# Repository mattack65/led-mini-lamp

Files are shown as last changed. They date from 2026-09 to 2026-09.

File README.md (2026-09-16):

# LED Mini Lamp

An open-source, 3D-printable LED lamp powered by WLED.

<p align="center">
  First WLED-effect candidate.
  Second WLED-effect candidate.
</p>

<p align="center">
  Third WLED-effect candidate.
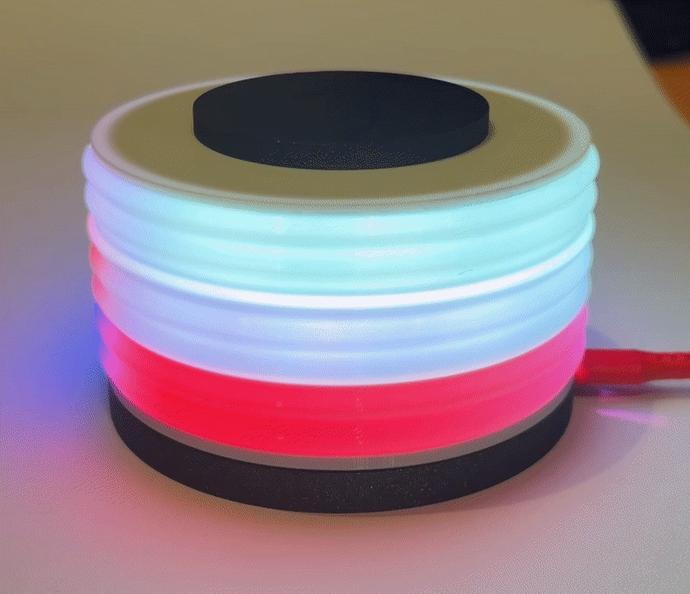
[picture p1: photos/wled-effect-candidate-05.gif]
Fifth WLED-effect candidate.
  
</p>

<p align="center">
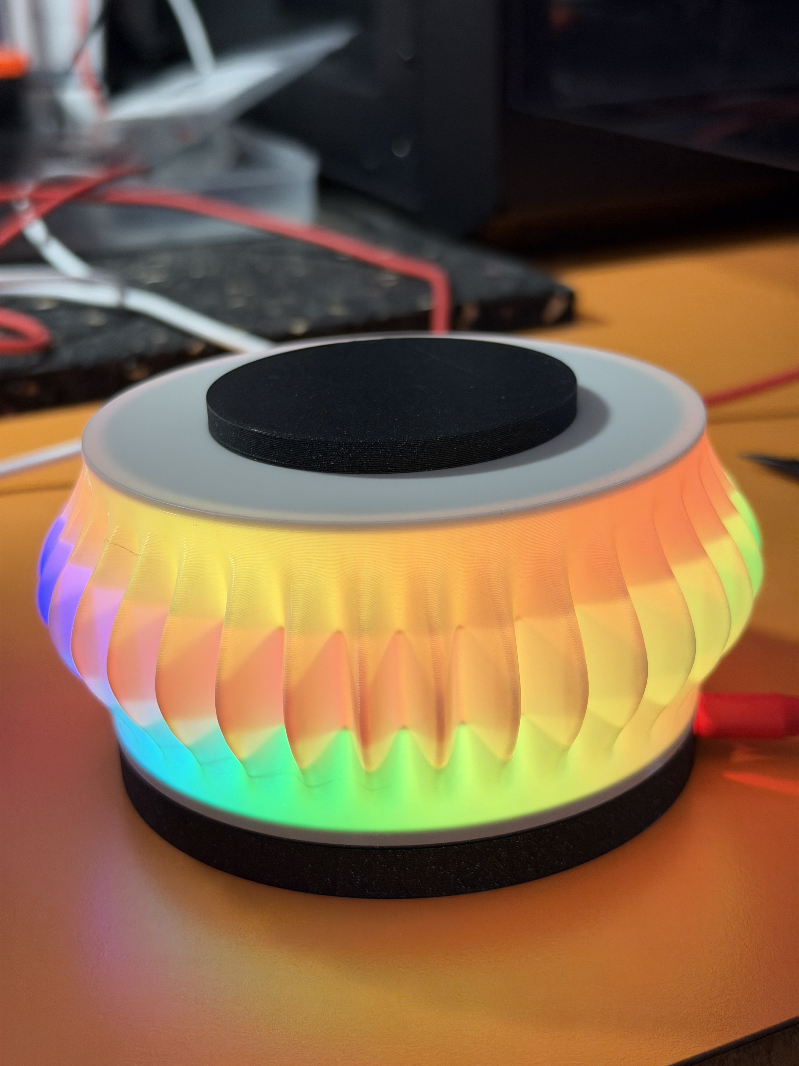
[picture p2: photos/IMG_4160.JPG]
LED Mini Lamp with a colourful WLED effect.
  
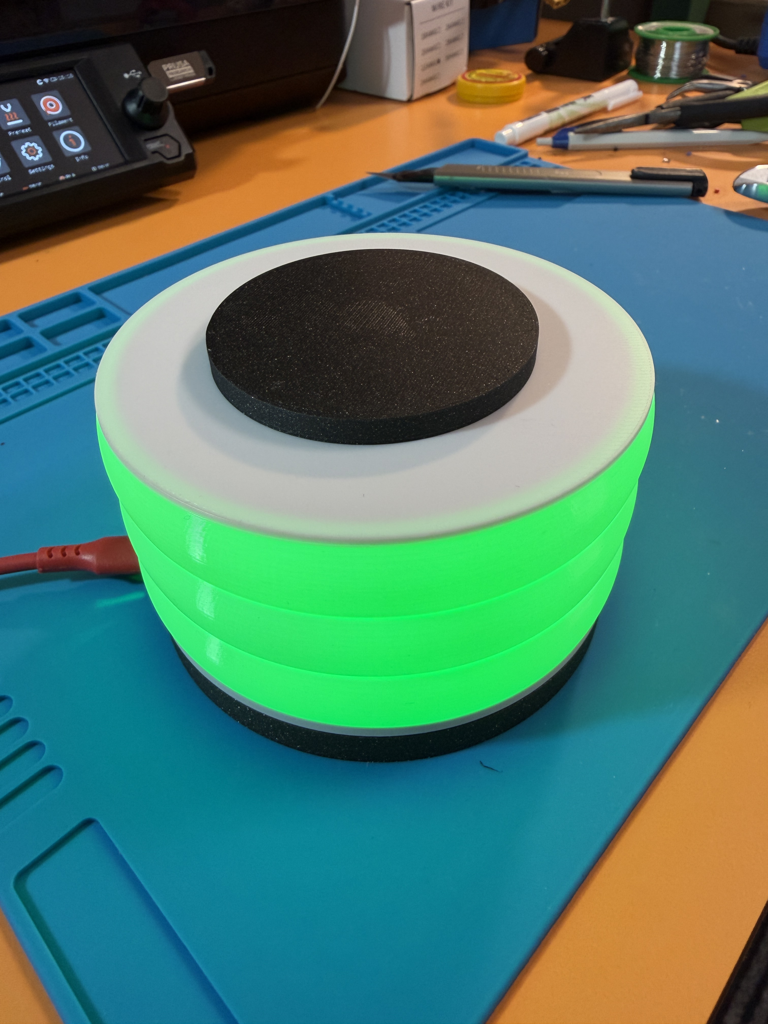
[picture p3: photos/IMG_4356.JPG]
LED Mini Lamp illuminated in green.
  
</p>

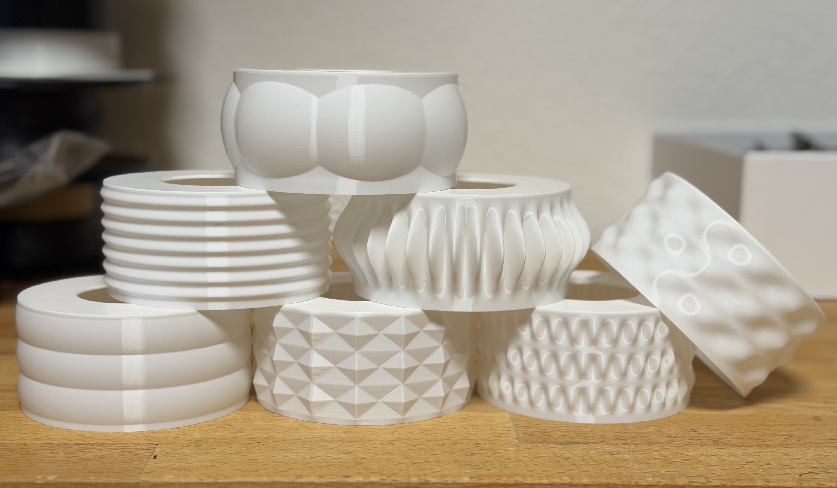
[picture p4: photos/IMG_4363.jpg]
The seven available white PLA diffusor designs.


## Start here

- [Bill of materials](docs/bom.md)
- [Printing the PLA parts](docs/printing.md)
- [Installing WLED firmware](docs/install-wled.md)
- [Setting up WLED](docs/wled-setup.md)
- [Assembly](docs/assembly.md)
- [Using your lamp](docs/using-your-lamp.md)

## Licence

This project is licensed under [CC BY-SA 4.0](LICENSE.md).

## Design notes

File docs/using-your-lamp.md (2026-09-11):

# Using your lamp

Control the lamp with the [WLED app](wled-setup.md#app-and-first-connection)
or by opening its WLED address in a browser.

## Colours and effects

Open the **Colors** tab to choose colours and palettes. Open the **Effects**
tab to browse animations, then adjust brightness, speed, and intensity until
you find a look you like.

## Save presets

Presets save a complete look: colours, effect, brightness, and other current
settings. They are useful for switching between favourite moods with one tap.

1. Set the lamp exactly as you like it.
2. Open the **Presets** tab and choose **Create Preset**.
3. Give it a meaningful name, such as `Warm evening` or `Party`.
4. Save the current state.

Select a saved preset at any time to restore it. You can also create a
playlist to cycle through multiple presets automatically.

## On and off presets

Presets can also run a command rather than save a lighting look. In the
**Presets** tab, choose **Create Preset**, turn off **Use current state**, and
enter one of these API commands:

| Command | Result |
| --- | --- |
| `T=1` | Turn the lamp on, restoring the last-used look. |
| `T=0` | Turn the lamp off. |
| `T=2` | Toggle the lamp on or off. |

Save these with clear names such as `Lamp on` and `Lamp off`. They can be
selected manually, used in playlists, or triggered by a schedule.

## Turn on at sunset

1. Create and save the preset you want the lamp to use at sunset. To simply
   restore the last-used look, create a `T=1` on preset instead. Also create a
   `T=0` off preset for the time you want the lamp to switch off.
2. Open **Config → Time & Macros**.
3. Set the correct time zone and enable time synchronisation (NTP).
4. Set your location so WLED can calculate local sunrise and sunset. When
   using a browser, the **Get Location** button can fill this in.
5. Under **Time-Controlled Presets**, add a **Sunset** timer, select your
   preset, choose the days of the week, and save.

Use the minutes field to make the lamp switch on before or after sunset. Add a
second timer for sunrise, sunset, or a regular time and select the `T=0` off
preset to switch it off automatically.

## Other useful WLED features

- **Nightlight:** have the lamp fade itself off after a chosen duration.
- **Boot preset:** choose a preset that is applied automatically whenever the
  lamp receives power.
- **Playlists:** create a slow, changing ambience from several presets.
- **Home Assistant:** WLED has native Home Assistant discovery, so the lamp
  can be added to an existing smart-home setup.

WLED has many more options; its [official documentation](https://kno.wled.ge/)
is an excellent place to explore once the lamp is working.

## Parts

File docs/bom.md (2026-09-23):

# Bill of materials

## Electronics and consumables

Estimated costs are approximate, exclude shipping, and use EUR. AliExpress
prices and availability vary by destination and over time.

| Part | Quantity | Specification | Estimated cost | Notes / source |
| --- | ---: | --- | ---: | --- |
| ESP32 development board | 1 | Small, flat ESP32 board with USB port | ~€2.60 | Tested: LOLIN S2 Mini. ESP32-C3 Super Mini is planned for future builds. The board must fit inside the lamp base; boards larger than the S2 Mini may not fit. Use a board without pre-soldered pin headers or other protruding hardware. The USB port must remain accessible because it provides power and is used for setup. [Example ESP32-C3 SuperMini listing](https://www.aliexpress.com/item/1005011660038502.html) |
| Addressable LED strip | 1 | 35 LEDs; 60 LEDs/m; WS2812B ECO; IP30 | Under €2.00 | Tested: BTF-LIGHTING WS2812B ECO. The 60 LEDs/m spacing is required. 35 LEDs use about 60 cm of strip. ECO LEDs keep the full-white load suitable for ordinary USB power. [Find the exact specification on AliExpress](https://www.aliexpress.com/w/wholesale-ws2812b-eco-60-leds-m-ip30.html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) |
| Hook-up wire | 3 lengths | AWG22; about 7 cm each | ~€0.10 | Enough for the maximum LED current of 1.12 A. One wire each for 5 V, GND, and data. |
| Double-sided VHB tape | About 2 cm² | Suitable for electronics | ~€0.05 | Holds the ESP32 to the base. |
| Glue | A few drops | Suitable for the printed parts | ~€0.05 | Glues the clip unit into the top plug. |
| Solder | As needed | Electronics solder | ~€0.05 | The LED strip connects to the ESP32 with six solder joints. |
| 3D-printed parts | 1 set | Base, top plug, clip unit, three core structures, and one diffusor | ~€2.47 | See the [print files](../print-files/) and [print settings](printing.md). |
| **Total material cost** | **1 lamp** | **All parts above** | **Under €7.32** | Excludes the USB cable, power adapter, and soldering iron. |

## Power requirement

A USB cable and power adapter are required but intentionally not included in
the BOM: most builders already have a suitable set.

| Part | Quantity | Requirement | Estimated cost |
| --- | ---: | --- | ---: |
| USB cable and power adapter | 1 | 5 V; at least 1.5 A. Connects to the ESP32 USB port and powers the lamp. | Not included |

## Tools

| Tool | Quantity | Estimated cost | Notes |
| --- | ---: | ---: | --- |
| Soldering iron | 1 | Not included | Suitable for electronics soldering. |

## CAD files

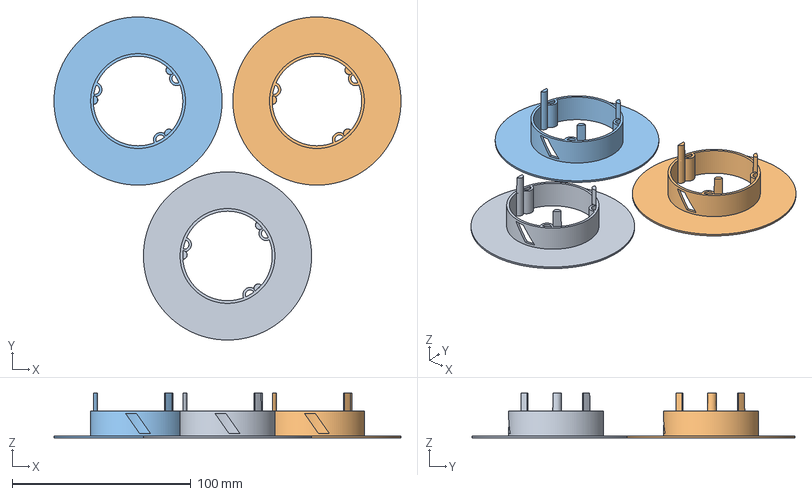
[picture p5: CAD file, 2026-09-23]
print-files/3mf/lamp_core_structure.3mf
194.0 x 180.6 x 25.0 mm

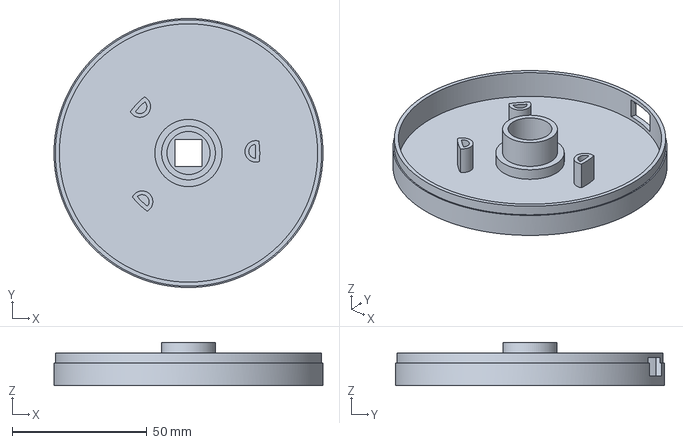
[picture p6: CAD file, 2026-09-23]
print-files/3mf/lamp_base.3mf
100.0 x 100.0 x 16.0 mm

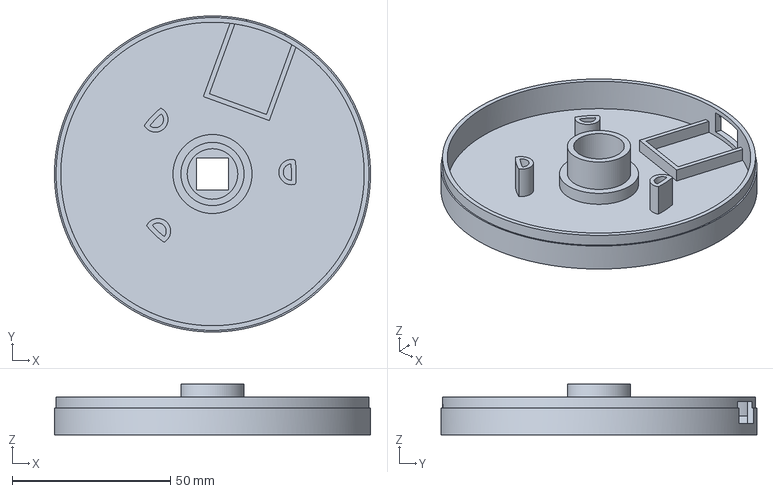
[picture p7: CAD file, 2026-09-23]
print-files/3mf/lamp_base_c3_super_mini.3mf
100.0 x 100.0 x 16.0 mm

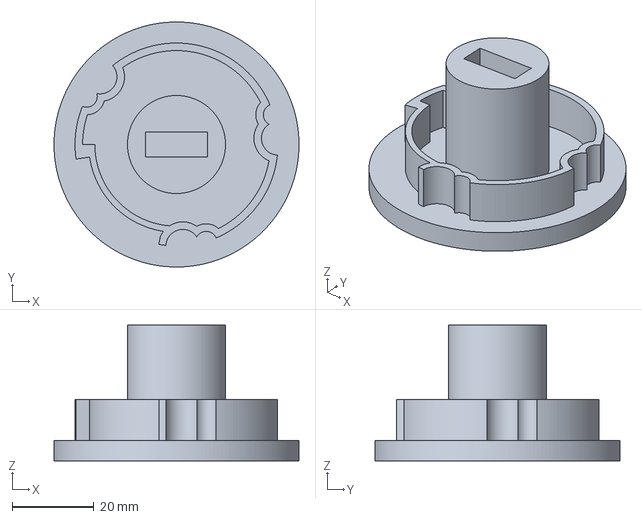
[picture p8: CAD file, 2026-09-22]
print-files/3mf/lamp_top_plug.3mf
60.0 x 60.0 x 33.3 mm

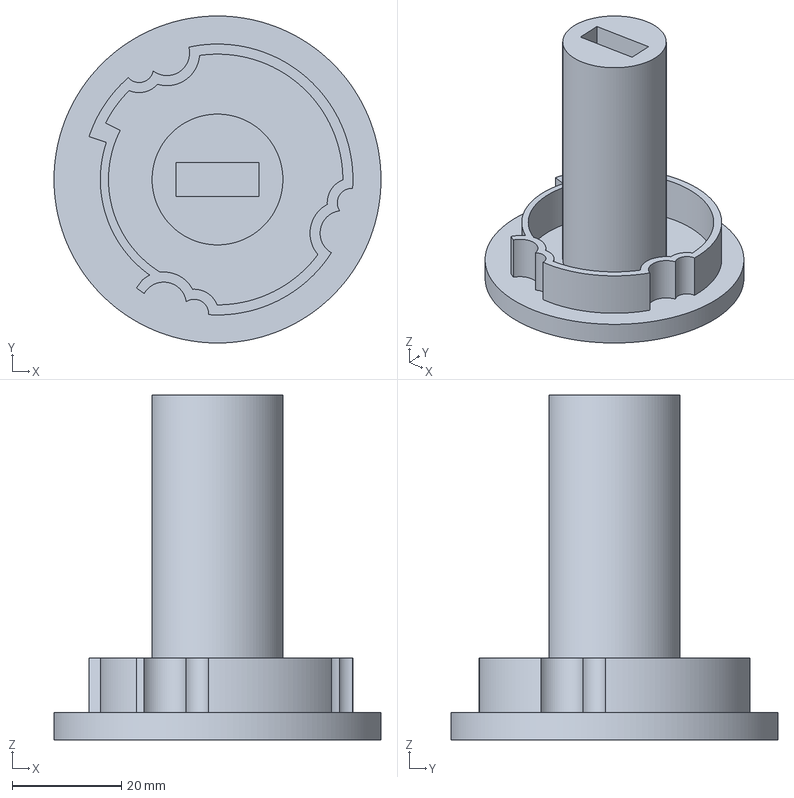
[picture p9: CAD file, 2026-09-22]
print-files/3mf/lamp_top_plug_5_layers.3mf
60.0 x 60.0 x 63.3 mm

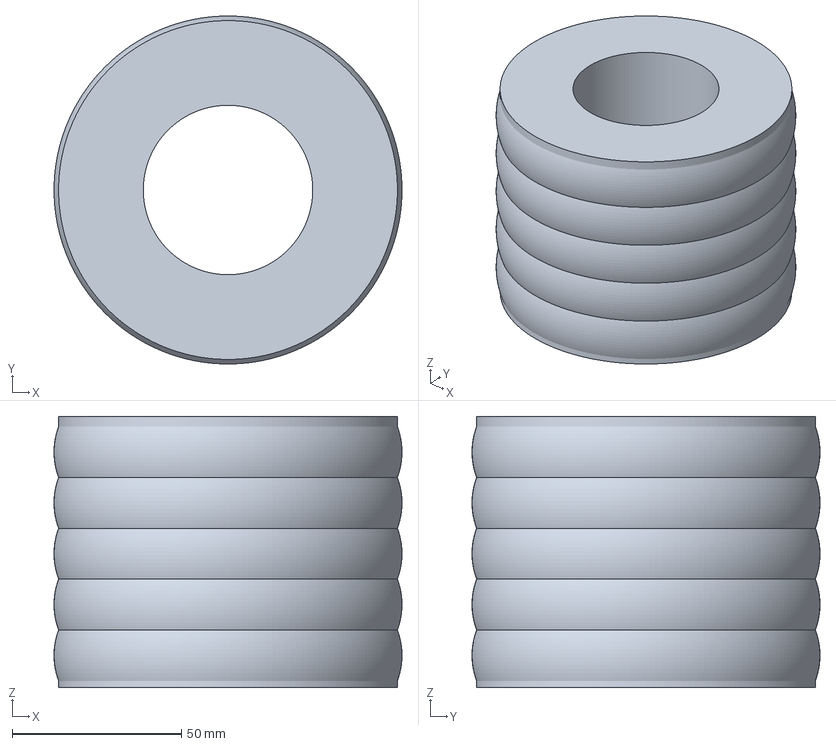
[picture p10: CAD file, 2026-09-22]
print-files/3mf/lamp_diffusor_bulges_5_layers.3mf
102.7 x 102.7 x 80.0 mm

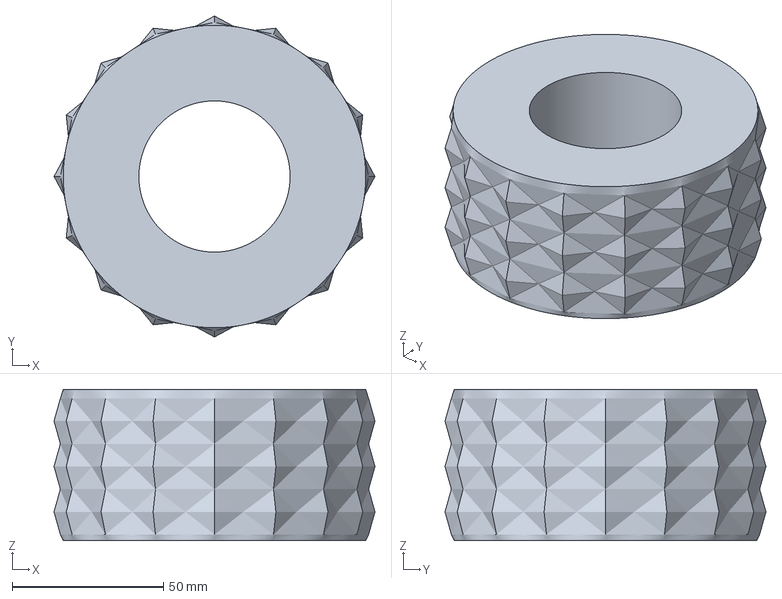
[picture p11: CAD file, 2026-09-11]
print-files/3mf/lamp_diffusor_starburst.3mf
106.2 x 106.2 x 50.0 mm

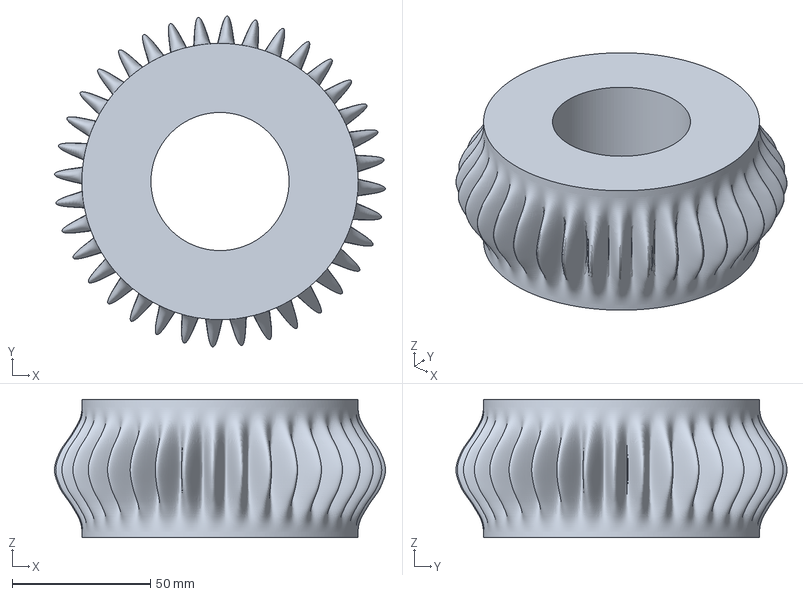
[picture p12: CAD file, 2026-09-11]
print-files/3mf/lamp_diffusor_single_sinusoidal_bulge.3mf
119.9 x 119.9 x 50.0 mm

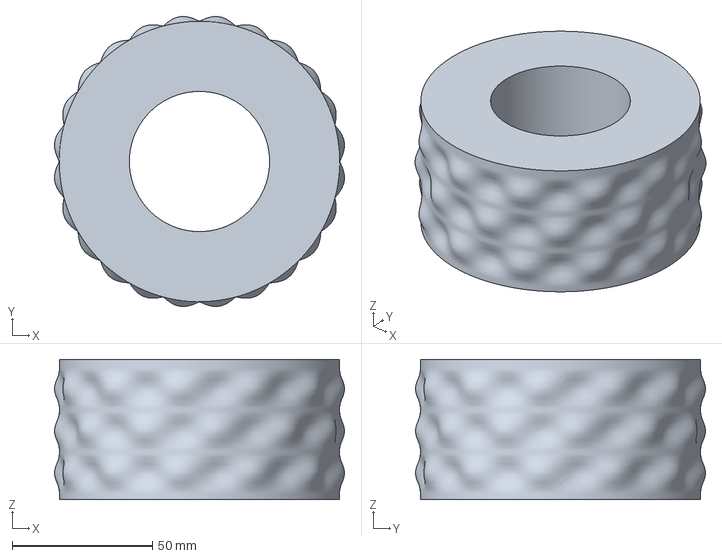
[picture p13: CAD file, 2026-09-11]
print-files/3mf/lamp_diffusor_sinusoidal_12_bubbles.3mf
103.4 x 103.4 x 50.0 mm

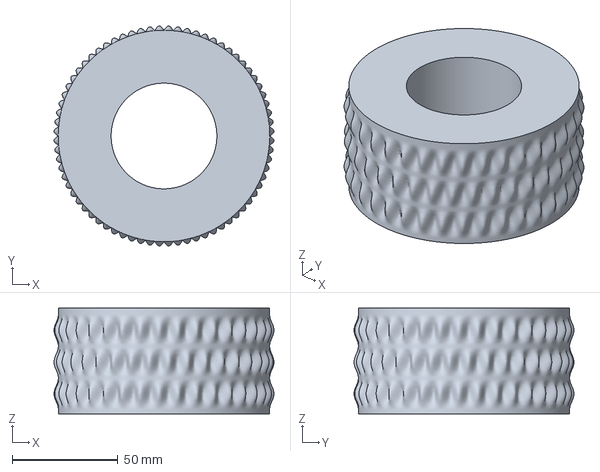
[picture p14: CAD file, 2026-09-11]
print-files/3mf/lamp_diffusor_sinusoidal_36_wave_x3.3mf
104.1 x 104.1 x 50.0 mm

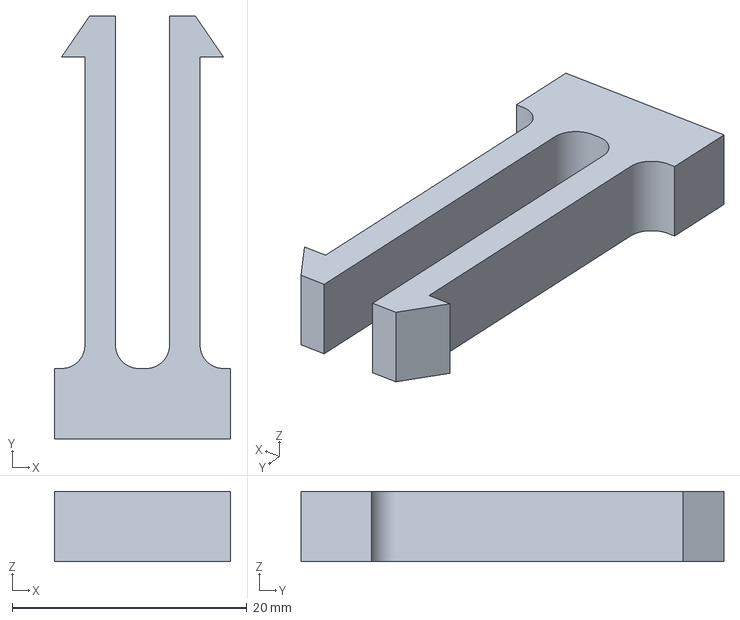
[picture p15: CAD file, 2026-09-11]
print-files/3mf/lamp_clip_unit.3mf
15.0 x 36.0 x 6.00 mm

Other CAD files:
print-files/3mf/lamp_diffusor_pumpkin.3mf
print-files/3mf/lamp_diffusor_seven_ripple.3mf
print-files/3mf/lamp_diffusor_bulges.3mf
print-files/stl/lamp_base.stl
print-files/stl/lamp_base_c3_super_mini.stl
print-files/stl/lamp_clip_unit.stl
print-files/stl/lamp_core_structure.stl
print-files/stl/lamp_diffusor_bulges.stl
print-files/stl/lamp_diffusor_bulges_5_layers.stl
print-files/stl/lamp_diffusor_pumpkin.stl
print-files/stl/lamp_diffusor_seven_ripple.stl
print-files/stl/lamp_diffusor_single_sinusoidal_bulge.stl
print-files/stl/lamp_diffusor_sinusoidal_12_bubbles.stl
print-files/stl/lamp_diffusor_sinusoidal_36_wave_x3.stl
print-files/stl/lamp_diffusor_starburst.stl
print-files/stl/lamp_top_plug.stl
print-files/stl/lamp_top_plug_5_layers.stl

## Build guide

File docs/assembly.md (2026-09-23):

# Assembly

This guide uses a LOLIN S2 Mini and a 35-LED WS2812B ECO strip. First install [WLED](install-wled.md) on the ESP32. The assembly photos use red for 5 V, black for GND, and purple for data.

## 1. Prepare the parts

The [printed parts](printing.md) are three core structures, a base, a top plug, a clip unit, and one diffusor. You will also need the controller, the LED strip, three short wires, double-sided VHB tape, glue, and soldering equipment.

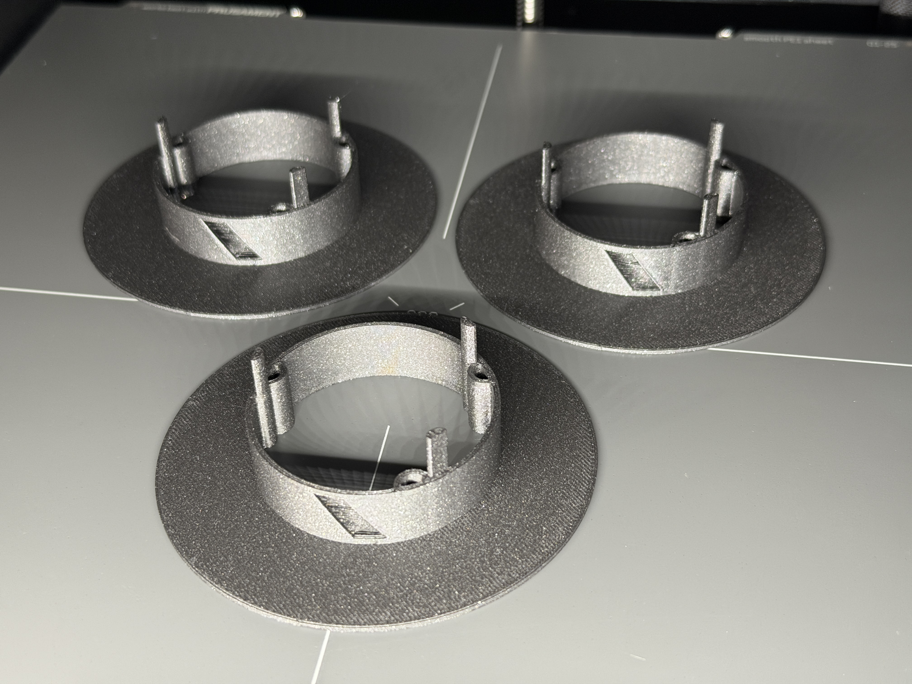
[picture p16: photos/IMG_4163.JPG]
Three printed core structures on the print plate.


The core structures.

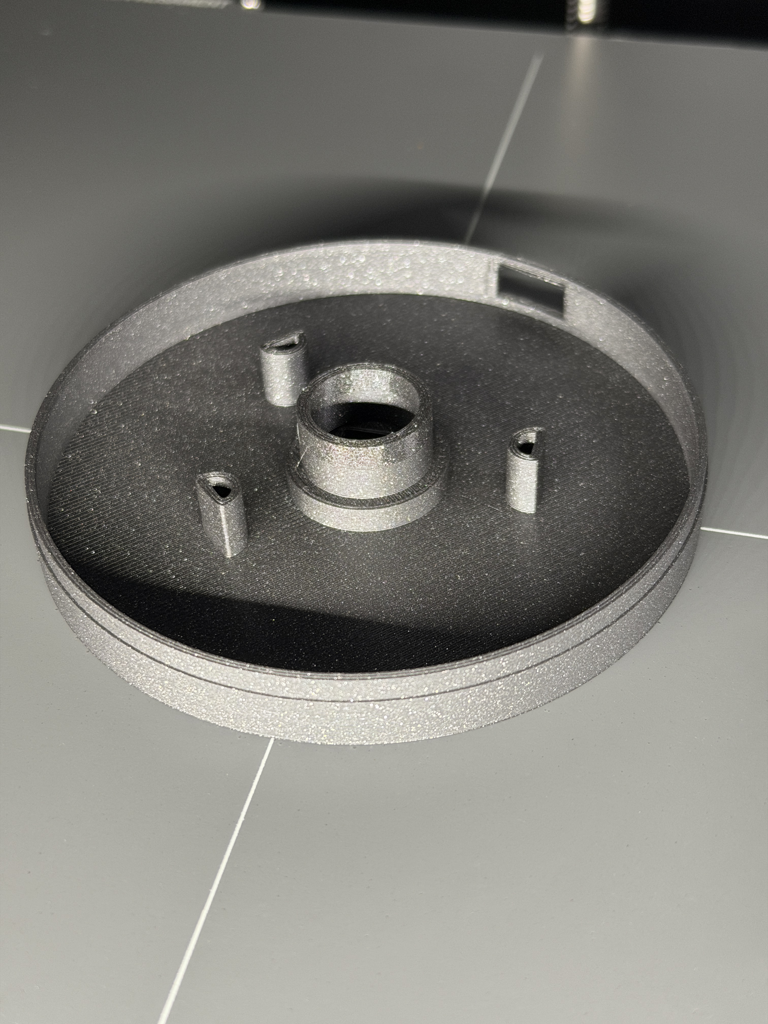
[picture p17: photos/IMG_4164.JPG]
The printed base, viewed from above.


The base holds the controller and leaves the USB port accessible at its edge.

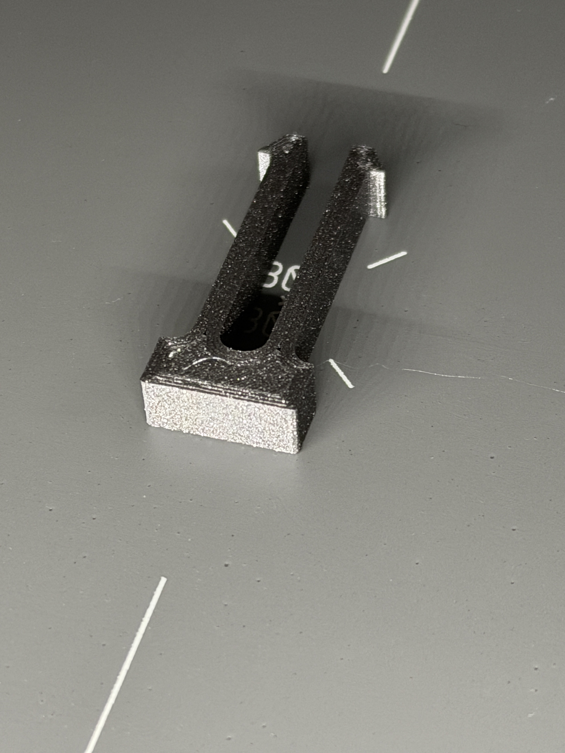
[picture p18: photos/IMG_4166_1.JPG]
The printed clip unit.


The clip unit will later be glued into the top plug.

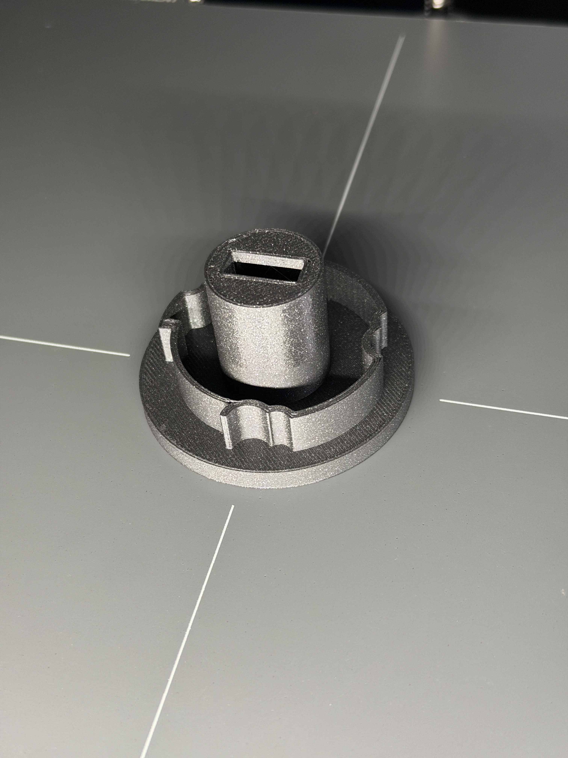
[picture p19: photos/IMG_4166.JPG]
The printed top plug.


The top plug closes the centre opening once the lamp is complete.

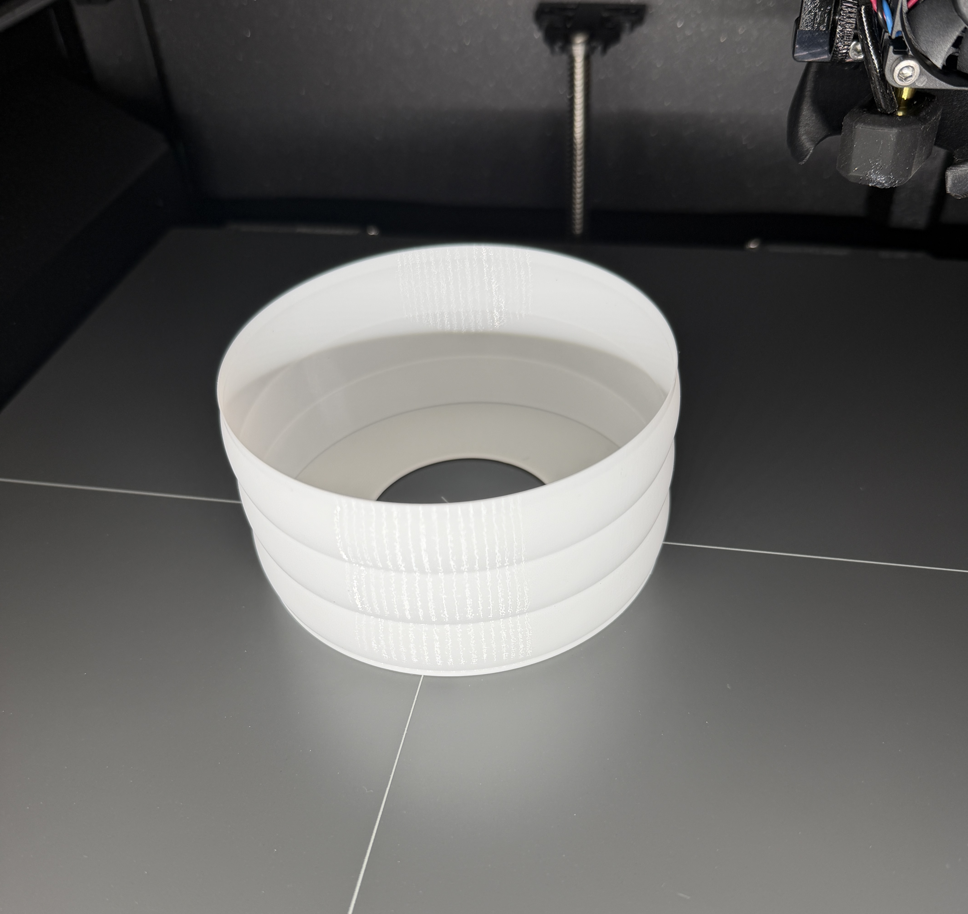
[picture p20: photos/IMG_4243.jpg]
A finished white PLA diffusor.


Choose one white-PLA diffusor for this lamp.

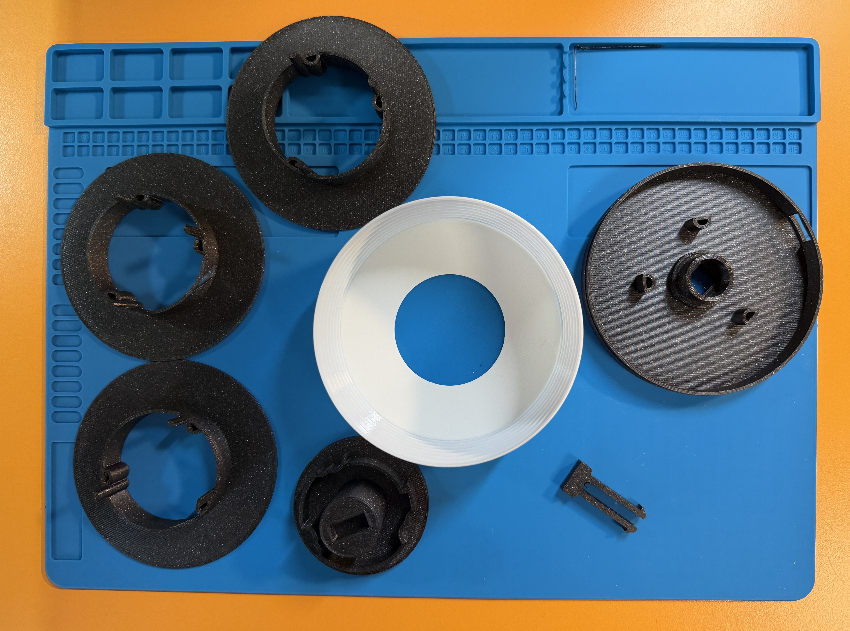
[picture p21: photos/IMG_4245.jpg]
All printed parts arranged before assembly.


All the 3D-printed parts.

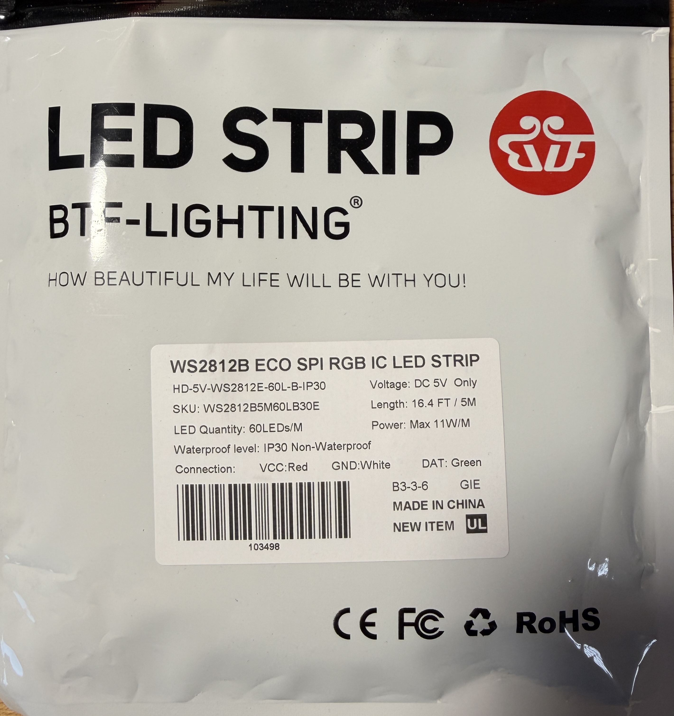
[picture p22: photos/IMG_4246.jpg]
BTF-LIGHTING WS2812B ECO LED strip packaging.


Use a 60 LEDs/m WS2812B ECO strip, as listed in the [BOM](bom.md).

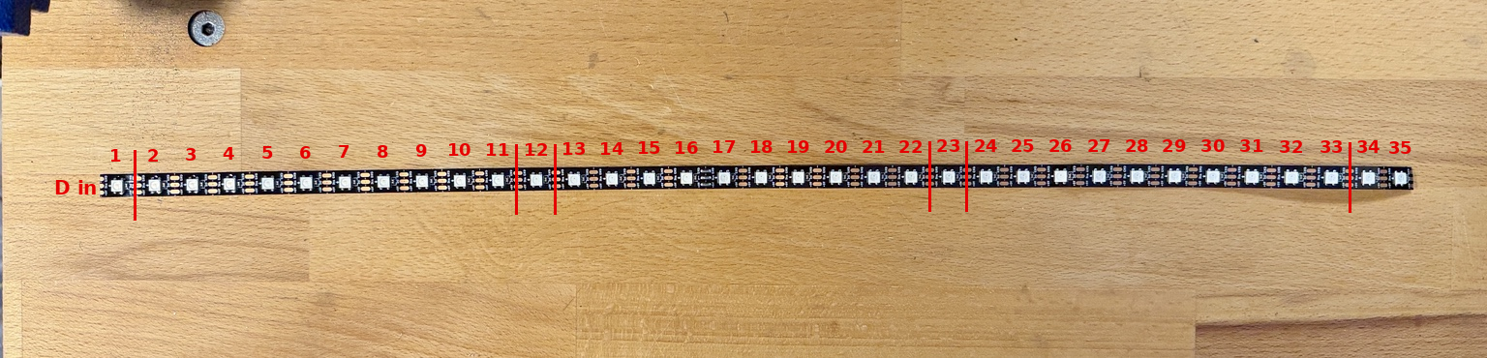
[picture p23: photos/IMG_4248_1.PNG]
A 35-LED length marked on the LED strip.


Some LED strips have factory-soldered joins between sections. The red lines mark the folds required when fitting the strip, counted from the "D in" end. Before cutting a 35-LED section, check that no factory-soldered join will land on a fold. If it would, cut one or two LEDs from the start of the roll first, then choose the next 35-LED section.

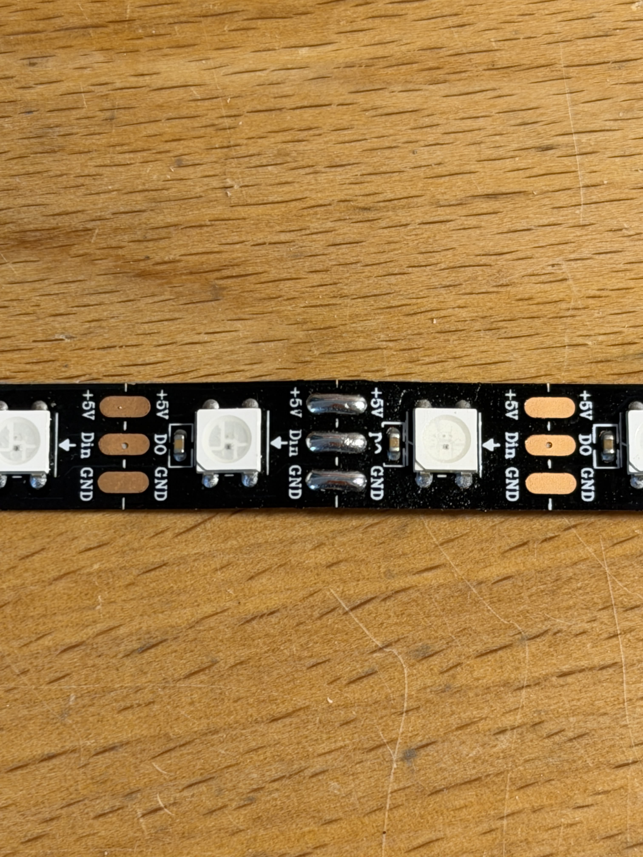
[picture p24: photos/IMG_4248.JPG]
Close-up of the LED strip.


This factory-soldered join is fine on a straight section of the strip, but it must not fall on one of the marked folding positions.

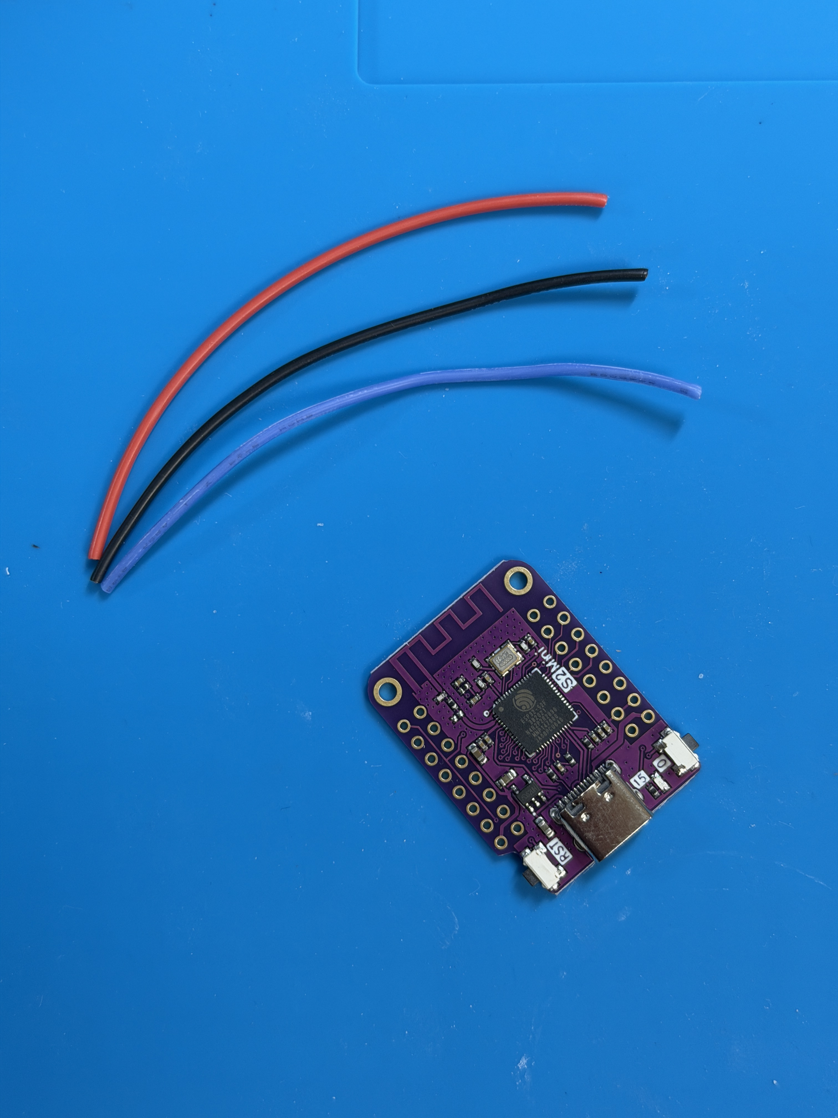
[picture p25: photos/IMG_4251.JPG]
LOLIN S2 Mini and three prepared wires.


Prepare three wires about 7 cm long: one each for 5 V, GND, and data.

## 2. Prepare the core and top clip

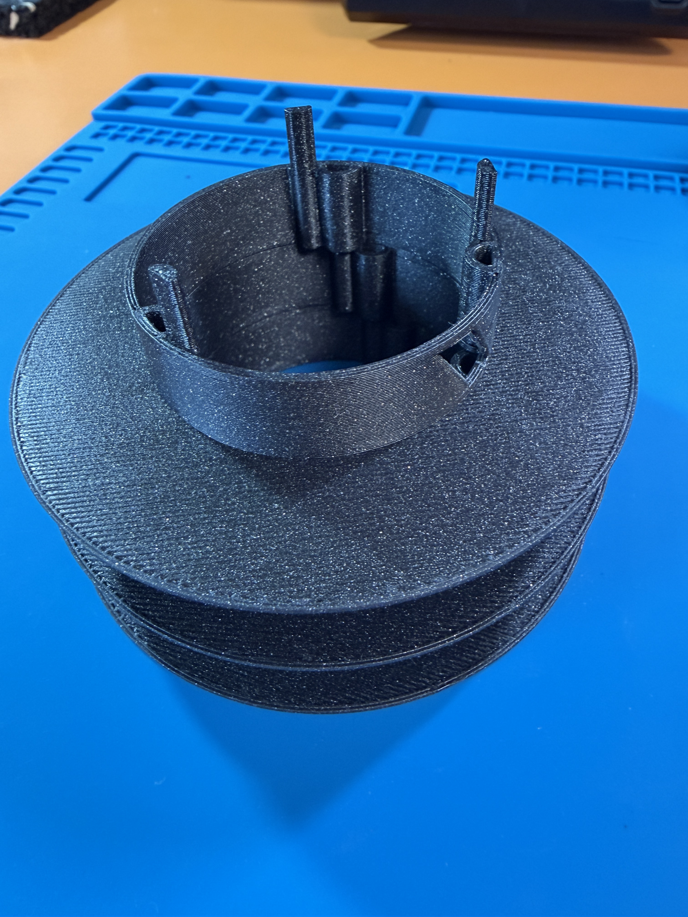
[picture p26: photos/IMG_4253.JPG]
The core structures assembled into the lamp frame.


Join the three core structures to make the internal frame. Their circular rings create the path for the LED strip.

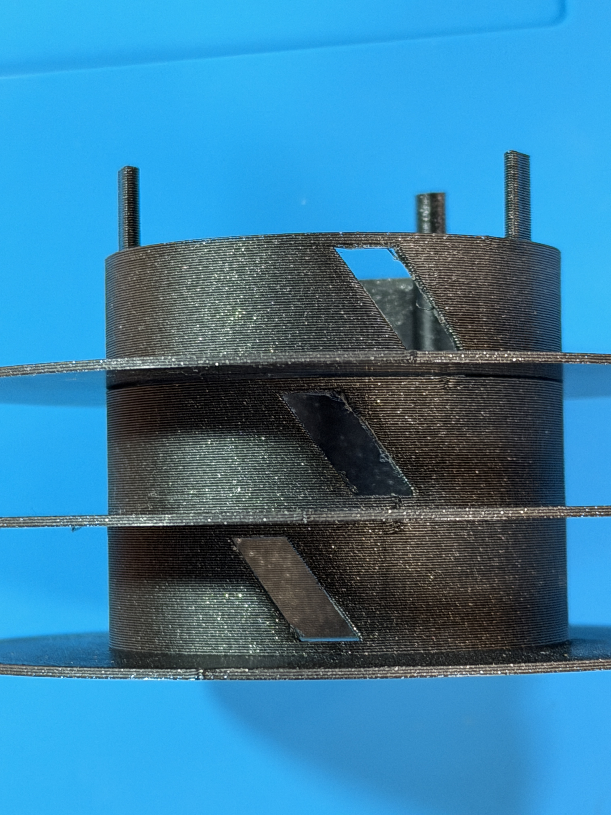
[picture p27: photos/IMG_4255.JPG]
Side view of the joined core structures.


Check that the core sections sit fully together.

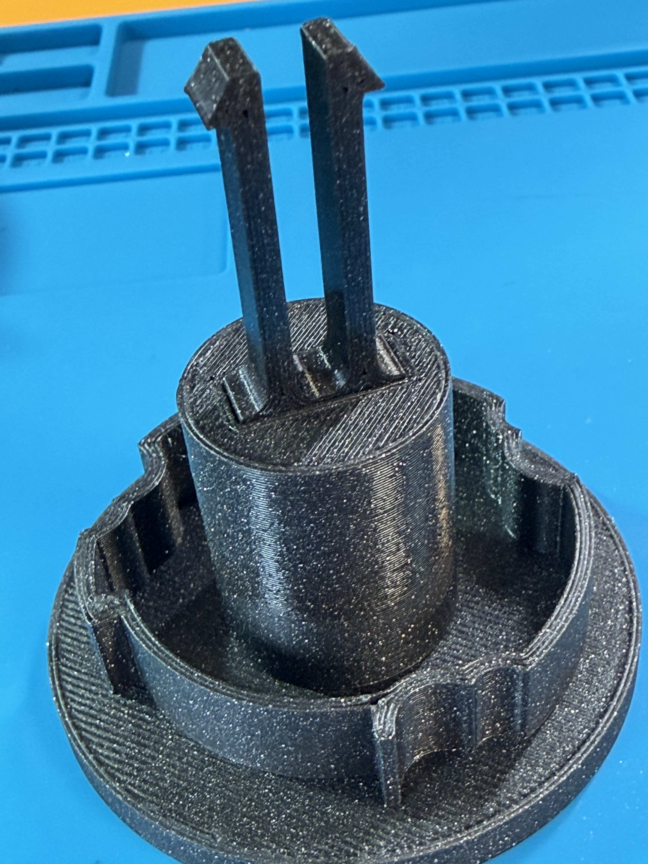
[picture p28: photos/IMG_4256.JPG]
Test-fitting the clip unit into the top plug.


Test-fit the clip into the top plug before gluing it in.

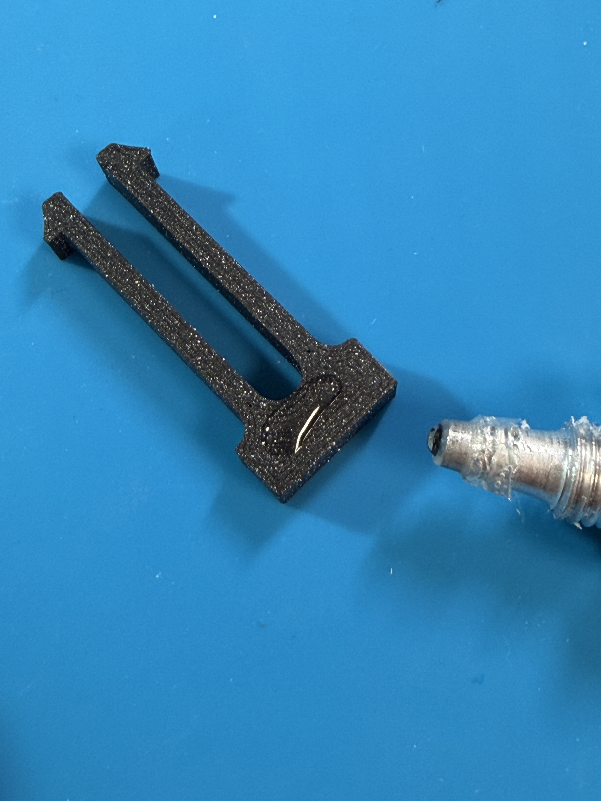
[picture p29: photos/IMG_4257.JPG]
The clip unit and a few drops of glue.


Use only a few drops of glue for the clip unit.

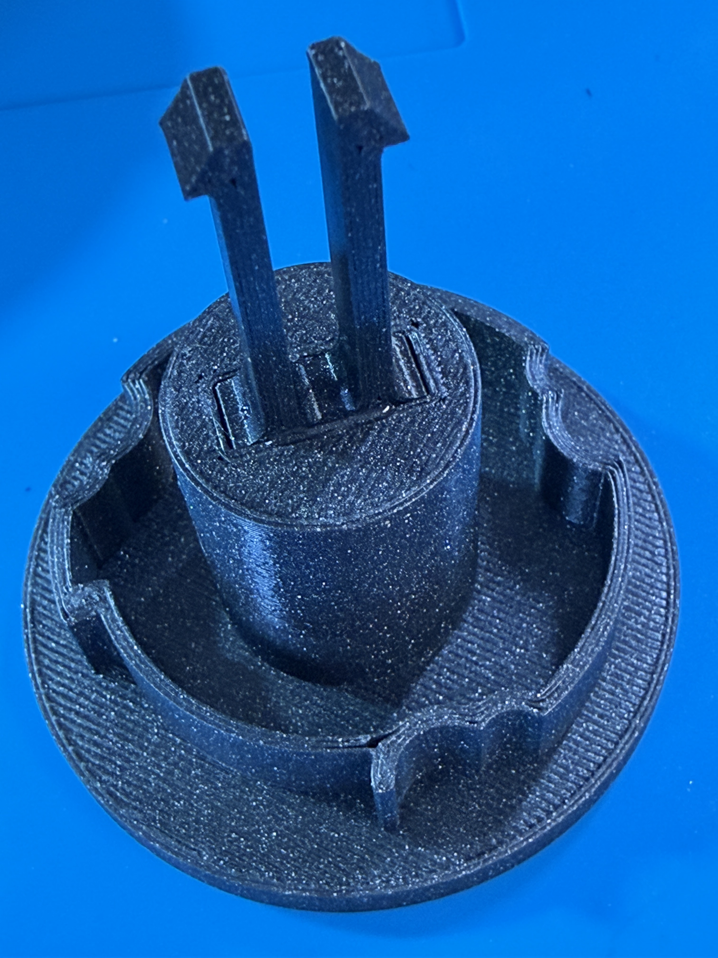
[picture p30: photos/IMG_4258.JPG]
The clip unit fitted into the top assembly.


Seat the clip unit squarely and press it all the way in. It should be flush.

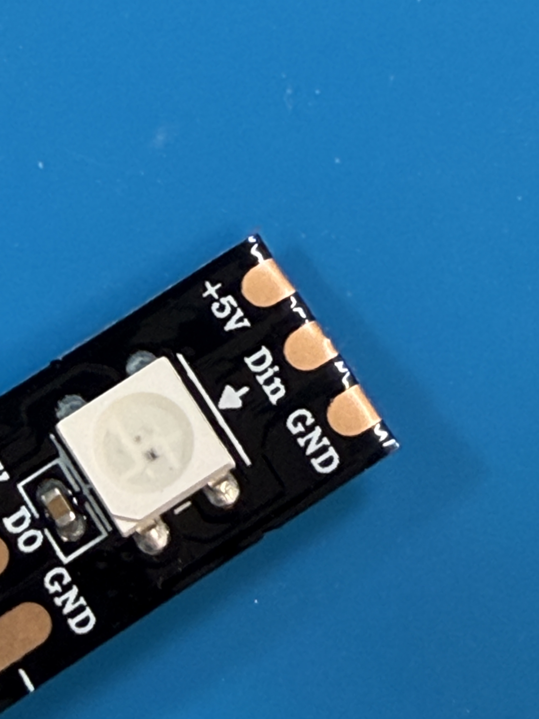
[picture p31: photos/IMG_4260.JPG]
LED strip pads at the data-input end.


The three pads are labelled +5V, D in, and GND. These are the pads to connect to the controller.

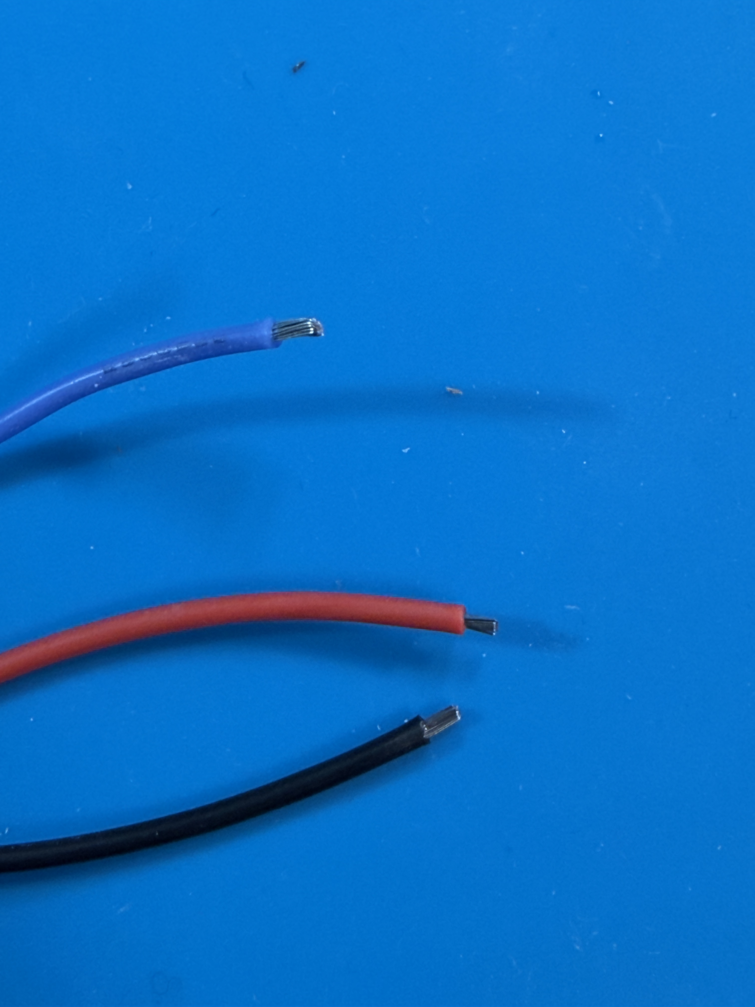
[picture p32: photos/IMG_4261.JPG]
Three wires with their ends stripped.


Strip only a few millimetres of insulation from each wire.

## 3. Solder the ESP32

The photos below show the pads on the LOLIN S2 Mini used in this build. On a different board, connect the same three signals: 5 V, GND, and the configured data GPIO.

| Function | LOLIN S2 Mini pad | LED strip pad | Wire shown |
| --- | --- | --- | --- |
| Power | VBUS | +5V | Red |
| Ground | GND | GND | Black |
| Data | 16/17 (GPIO 16) | D in | Purple |

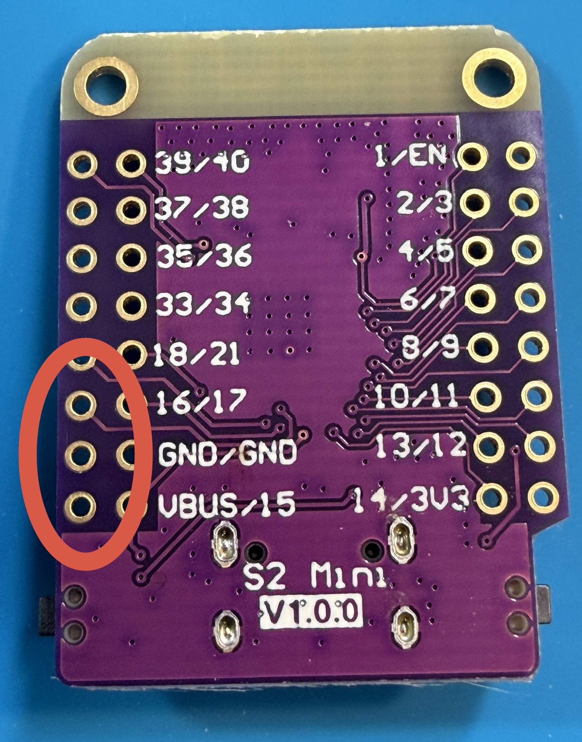
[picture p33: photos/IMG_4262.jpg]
LOLIN S2 Mini pads selected for the three connections.


The highlighted pads are, from top to bottom, GPIO 16, GND, and VBUS.

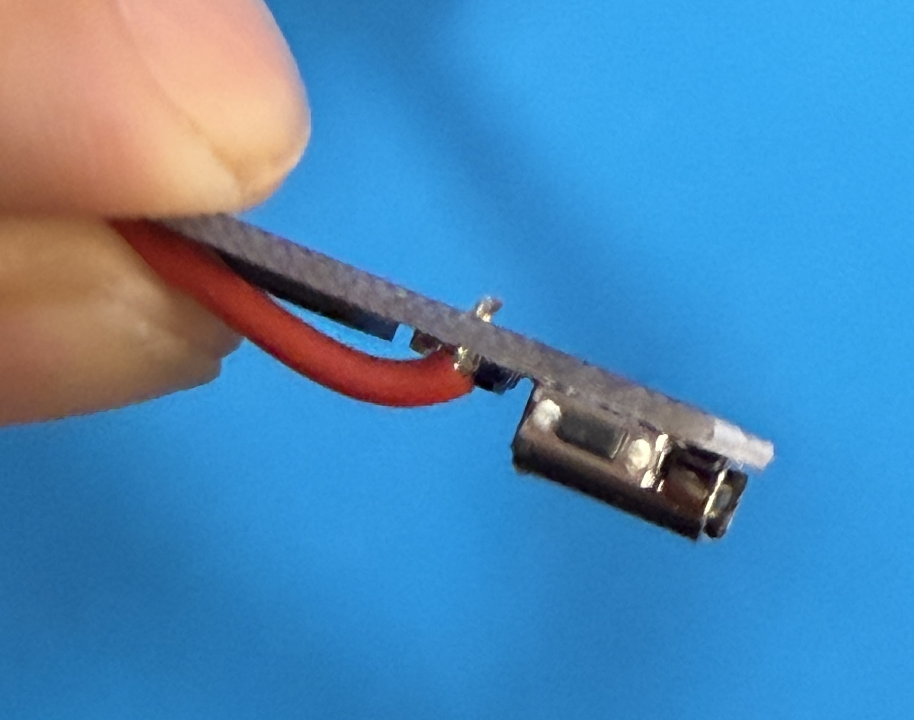
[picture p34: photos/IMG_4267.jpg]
Threading a wire through the ESP32 pad.


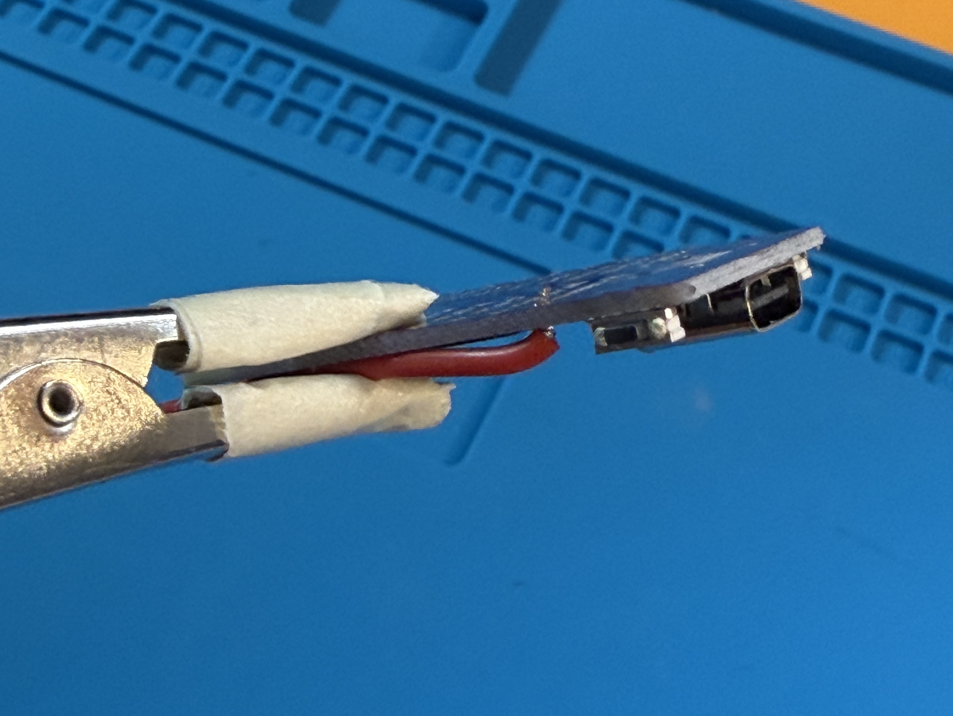
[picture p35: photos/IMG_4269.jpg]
A wire held ready for soldering.


A helping hand or similar holder makes these small solder joints much easier.

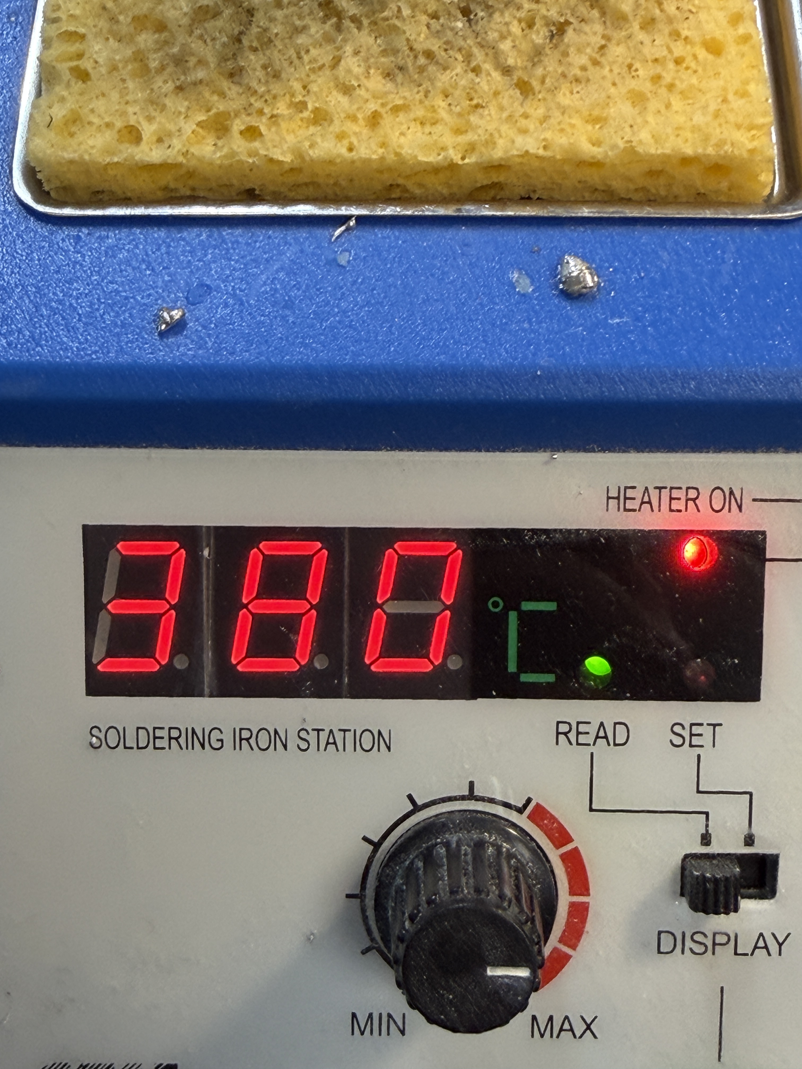
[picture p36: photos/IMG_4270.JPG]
Soldering-iron temperature set for the joint.


Heat your iron to about 380 °C.

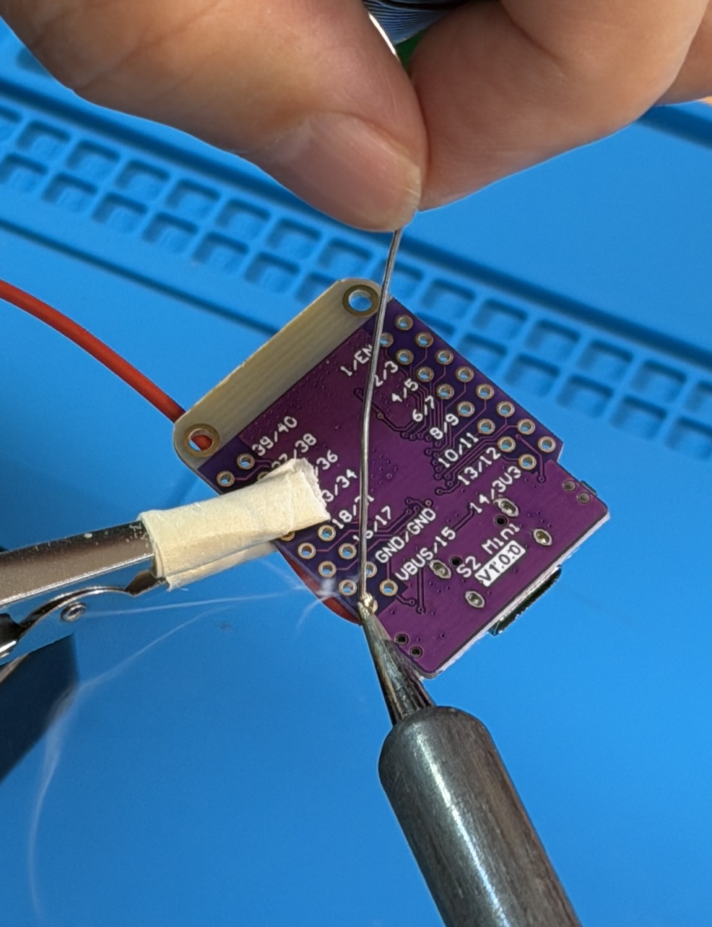
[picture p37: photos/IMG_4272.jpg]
Soldering the 5 V wire to the ESP32.


Solder the red 5 V wire to VBUS.

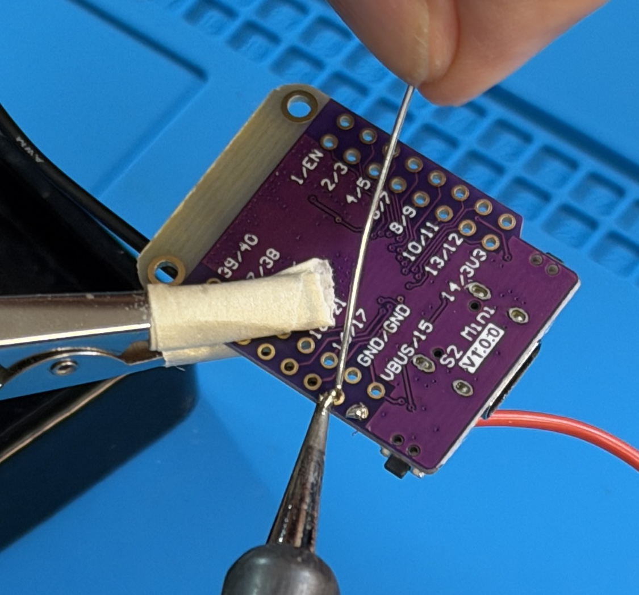
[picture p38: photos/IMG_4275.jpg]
Soldering the ground wire to the ESP32.


Solder the black wire to GND.

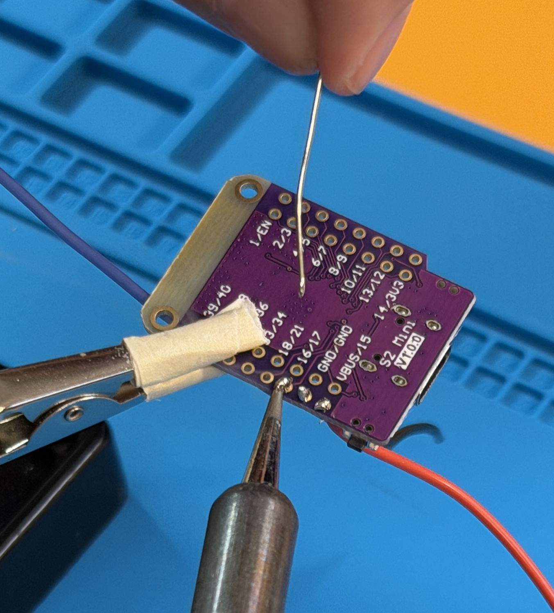
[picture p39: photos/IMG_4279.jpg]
Soldering the data wire to the ESP32.


Solder the purple data wire to GPIO 16.

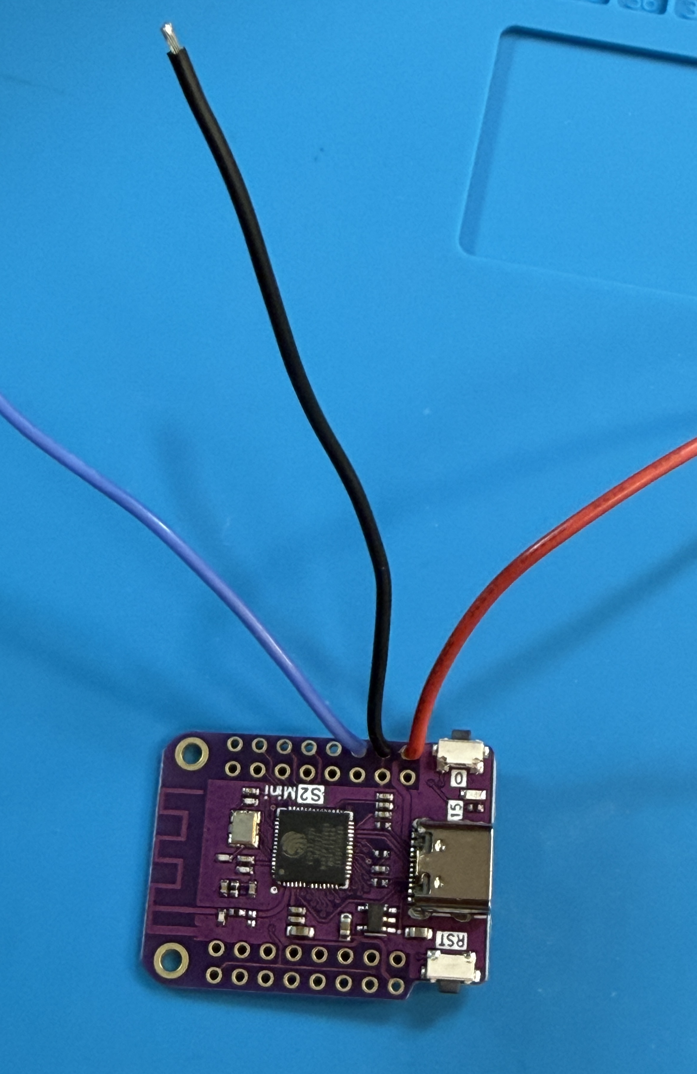
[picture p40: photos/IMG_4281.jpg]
ESP32 with all three wires connected.


The controller wiring is complete: red to VBUS, black to GND, and purple to GPIO 16.

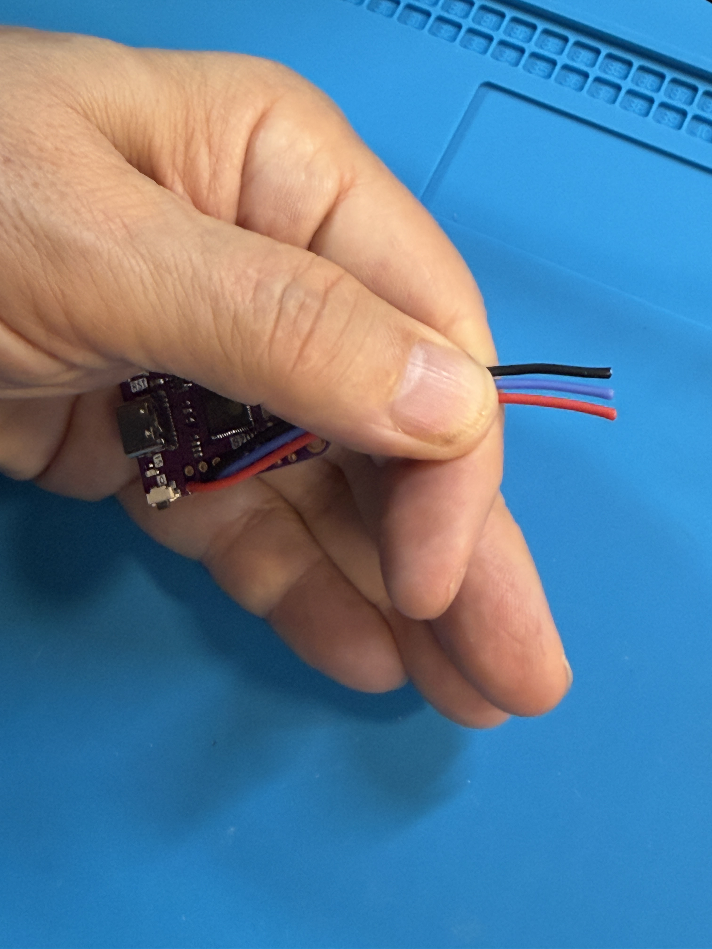
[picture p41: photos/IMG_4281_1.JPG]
Cutting the three wires to equal length.


Cut the free ends to the same length and arrange them in the correct order: red, purple, black.

## 4. Solder the LED strip

Solder the other ends of the same three wires to the +5V, D in, and GND pads at the **input** end of the LED strip. The three controller joints and the three strip joints are the six solder joints required for the lamp.

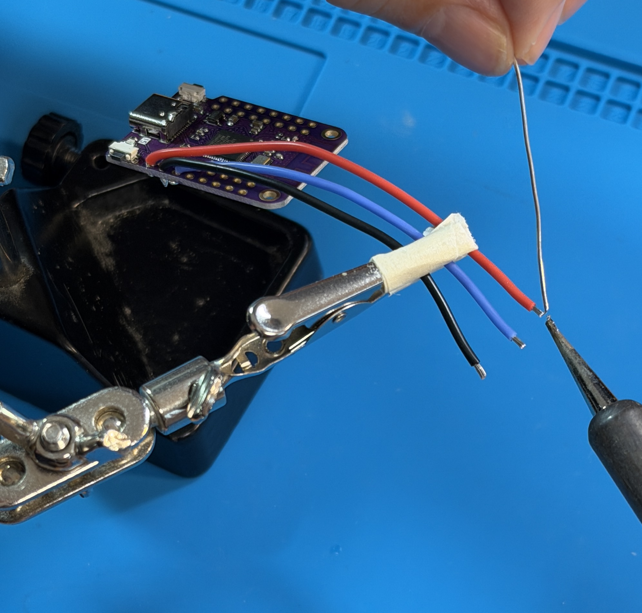
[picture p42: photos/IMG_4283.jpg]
Preparing the wires for the LED-strip connection.


Tin the ends of the wires.

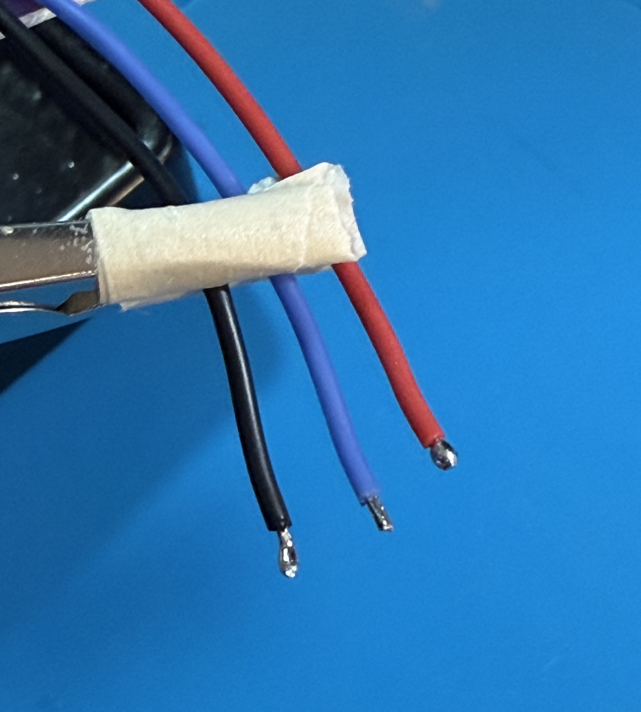
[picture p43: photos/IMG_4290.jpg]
The three wire ends tinned and ready.


A small amount of solder on each end is enough.

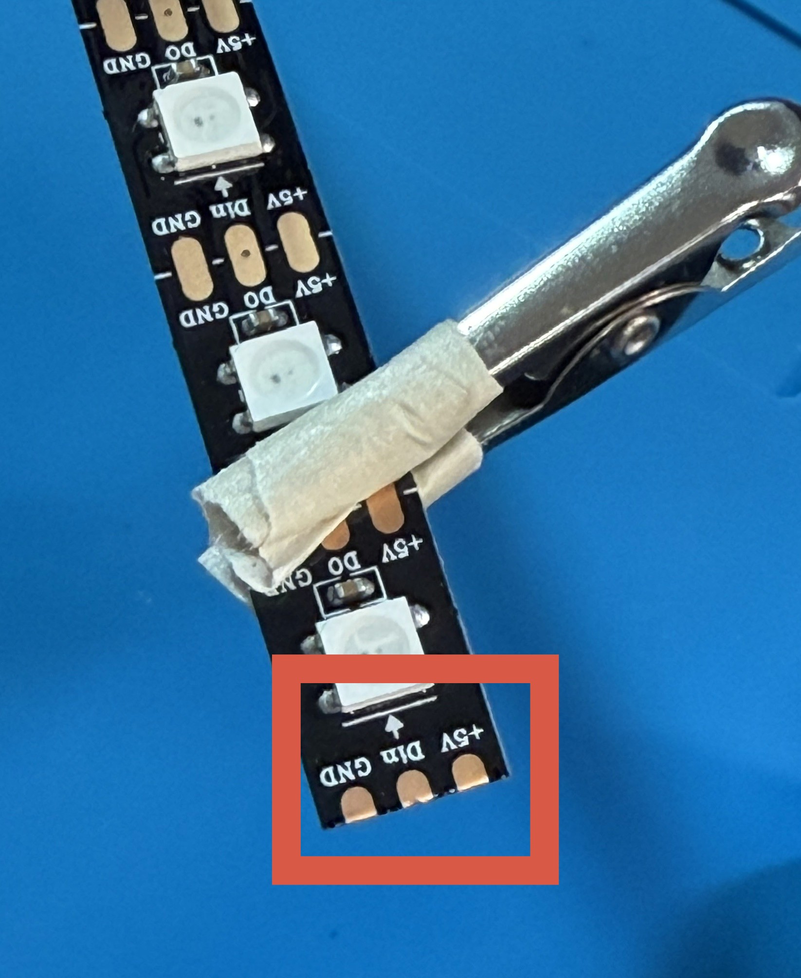
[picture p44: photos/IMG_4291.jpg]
LED-strip input pads highlighted.


The three pads are labelled +5V, D in, and GND. These are the pads to connect to the controller. Use the end marked D in; the arrows point away from this input end. If you solder the strip from the wrong end, it will not work later.

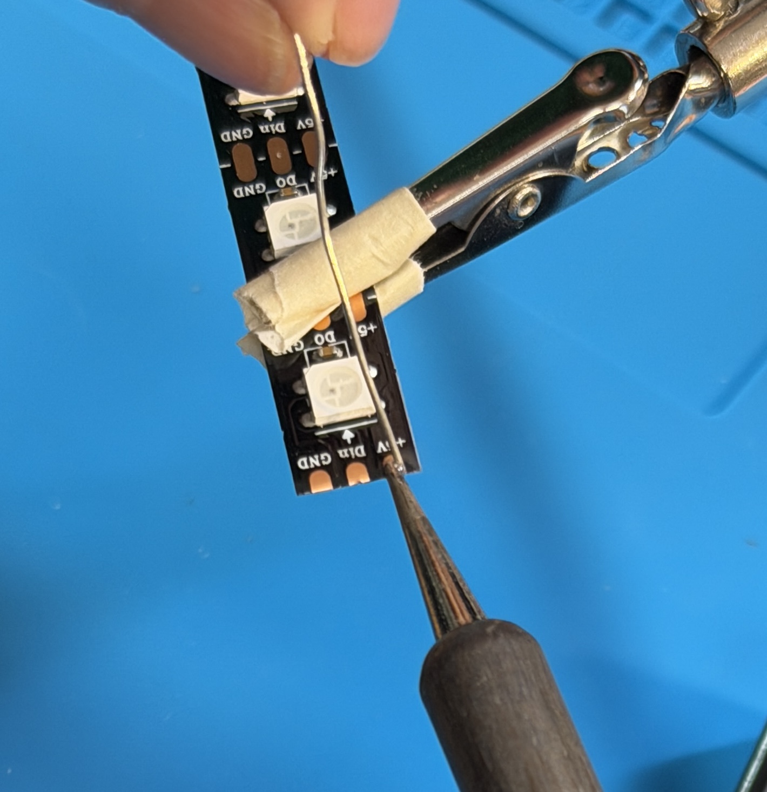
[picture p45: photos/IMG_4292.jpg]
Tinning an LED-strip pad.


Tin the copper pad briefly, without overheating the flexible strip.

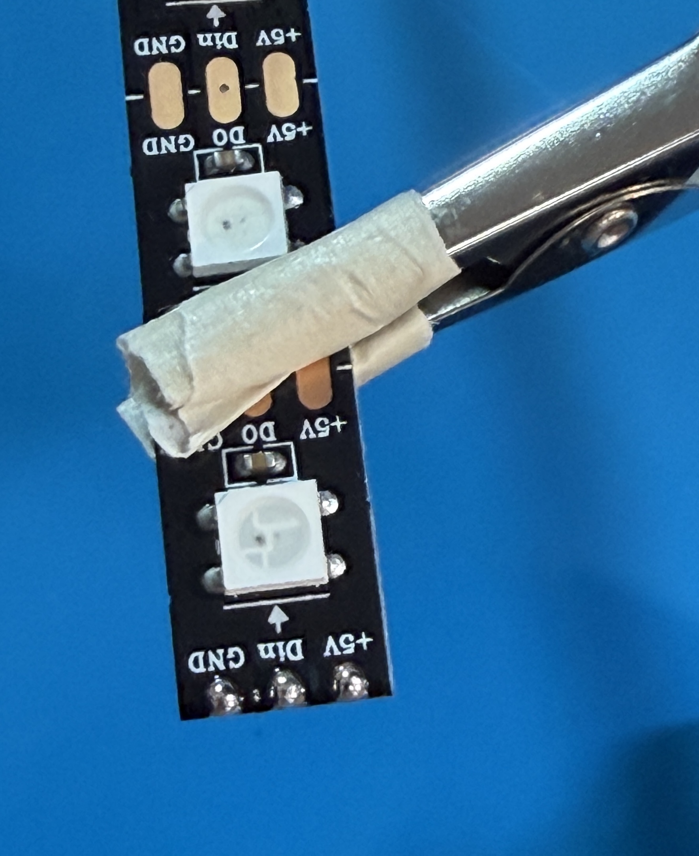
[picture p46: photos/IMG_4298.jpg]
Tinned LED-strip input pads.


The three pads are ready to receive the wires.

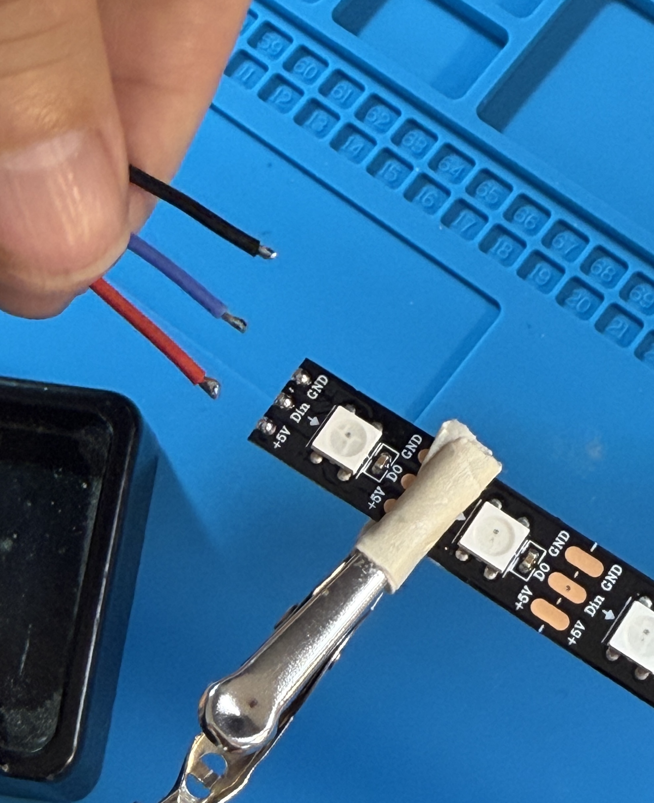
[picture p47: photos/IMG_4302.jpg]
Soldering a wire to the LED strip.


Hold the wire still until the solder joint has set.

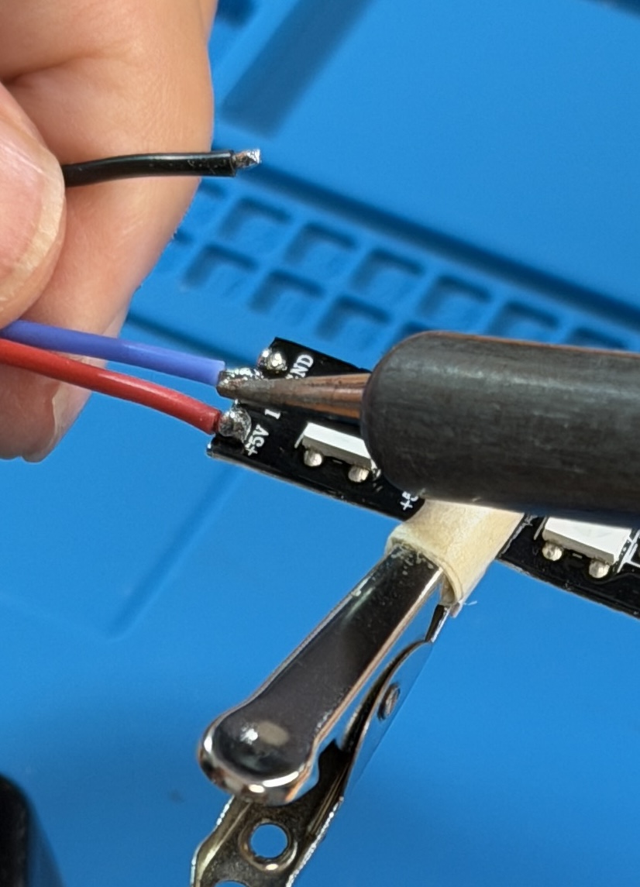
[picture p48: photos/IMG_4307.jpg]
Completing the LED-strip solder joints.


Repeat for the remaining two pads: red to +5V, purple to D in, and black to GND.

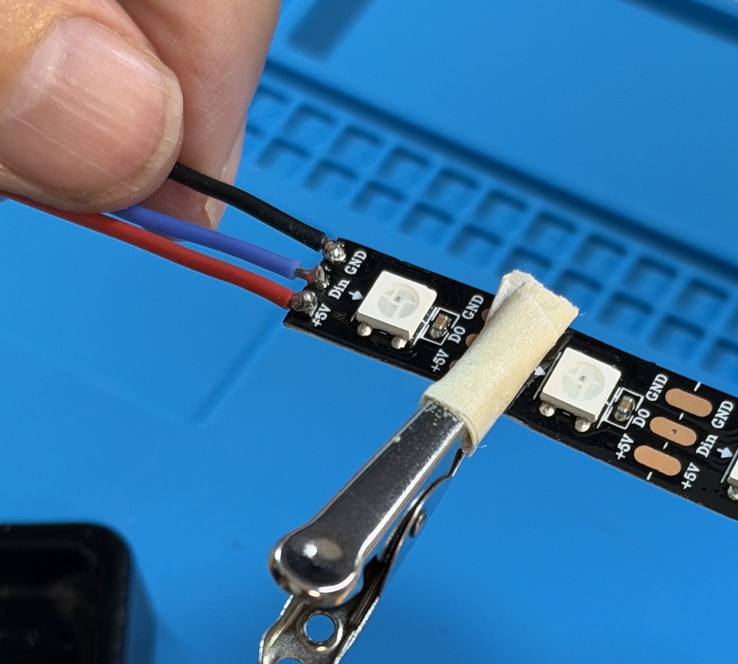
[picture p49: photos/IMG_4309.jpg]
Completed LED-strip wiring.


Check that the wires are firmly attached.

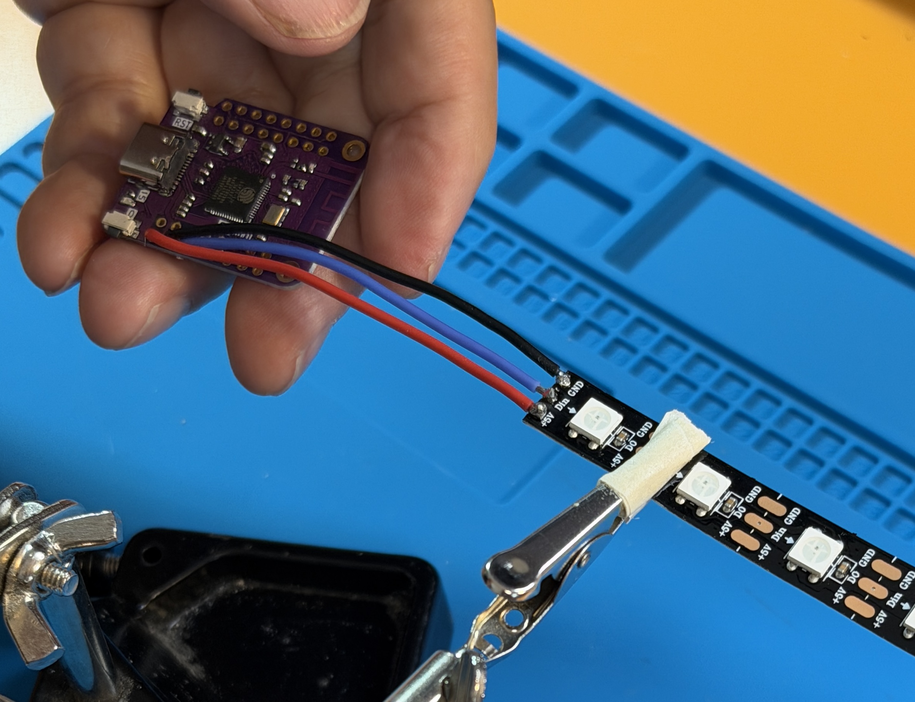
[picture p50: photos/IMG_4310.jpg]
The controller connected to the LED strip.


The electrical assembly is now complete. Connect USB power briefly to confirm that the strip responds and the LEDs turn on. With fresh WLED settings, the final five LEDs will probably stay off because the default is 30 LEDs. After configuring this lamp in WLED, the first and final two LEDs stay off as intended.

## 5. Fold and fit the LED strip

Start at the wired D in end and follow the route shown in the photos. Keep the backing paper on the long middle section. The strip will be folded **sharply** at each red line in the numbered photo above. Only the short adhesive sections at the beginning and end are exposed.

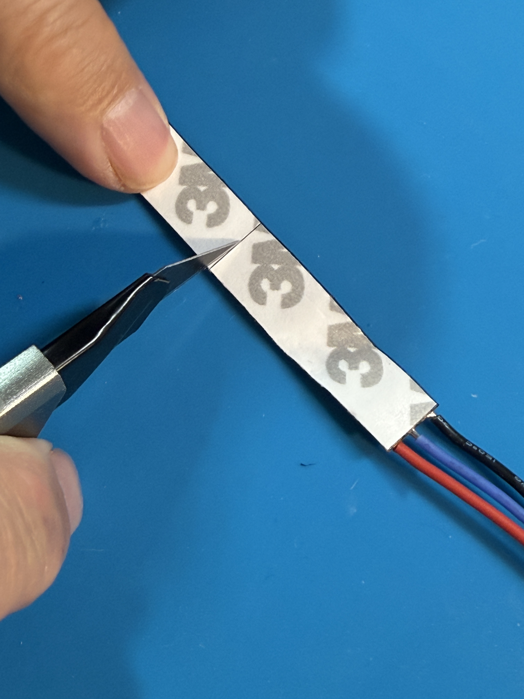
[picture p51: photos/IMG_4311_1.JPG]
Cutting the backing paper near the D in end.


Cut through the backing paper about 3 cm from the D in end, but leave the backing in place for now.

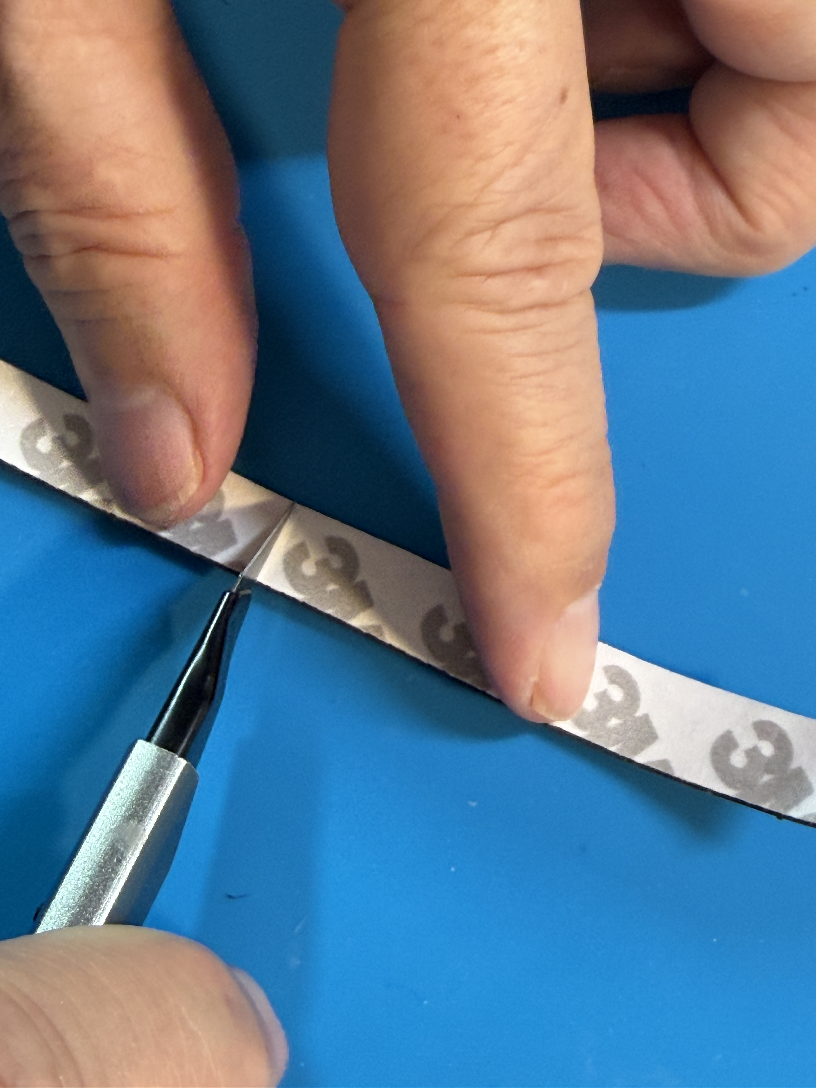
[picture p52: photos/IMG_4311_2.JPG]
Cutting the backing paper near the far end.


Cut through the backing paper about 5 cm from the far end. Leave the backing on the middle section of the strip.

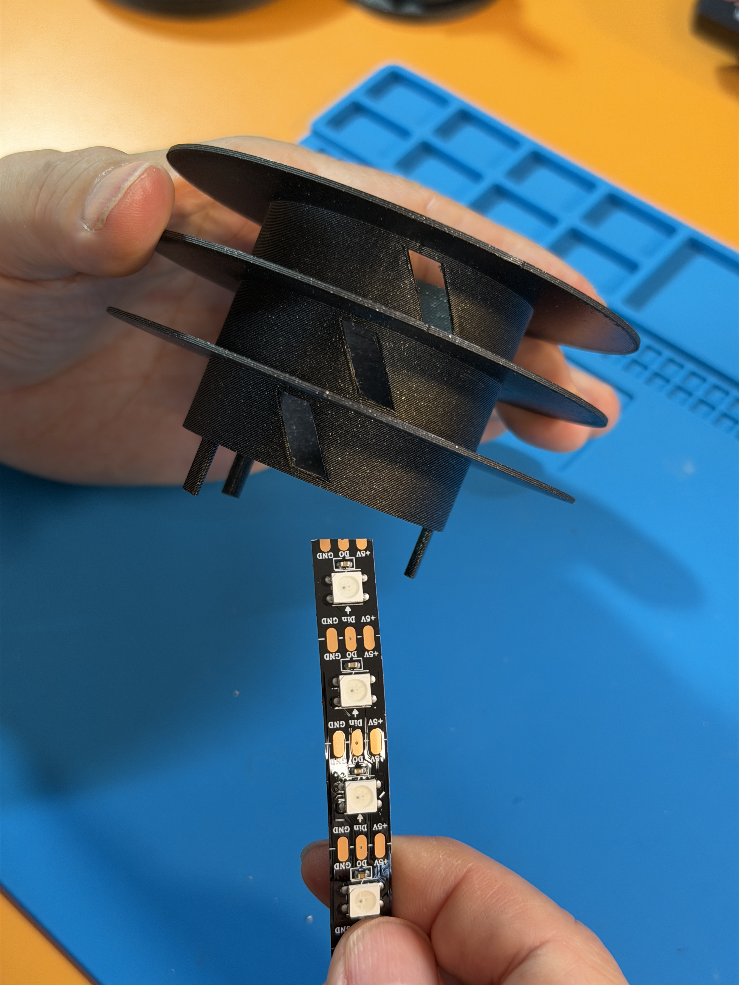
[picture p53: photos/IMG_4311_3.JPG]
Starting to route the LED strip through the core.


Start at the unsoldered end and thread the strip into the core as shown.

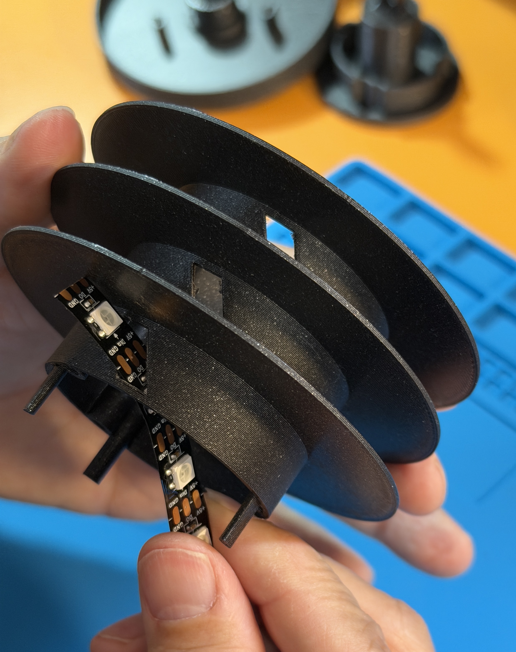
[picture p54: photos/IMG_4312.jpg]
Routing the first section of strip through the core.


Guide the strip through the first section of the core, with the LEDs facing outward.

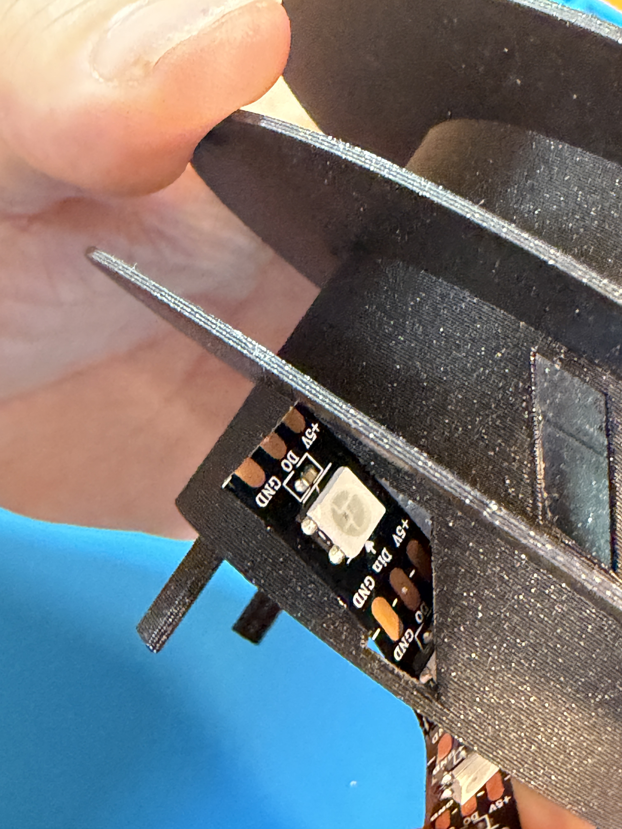
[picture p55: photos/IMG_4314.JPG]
Making a sharp fold in the LED strip.


Routing the strip around the core.

Fold the strip sharply around that first bend, so that one LED remains on the other side.

Bringing the wired end through the lower core.

Holding the LED strip while making the next fold.

A small clip can hold the strip temporarily while you place the LEDs.

Fitting the LED strip around the next core ring.

Route the strip around the first ring, then fold it sharply at the slot.

Folding the LED strip through the core.

Pass the strip through the core as shown.

LED strip positioned on the upper core ring.

It should look like this.

Backing paper still on the long middle section.

Continue this fold-and-route pattern around the next two rings.

Making another sharp fold in the LED strip.

LED strip following the final core ring.

Routing the last part of the LED strip.

Completed routing of the LED strip around the core.

The physical strip has 35 LEDs. The first and final two are attachment points; WLED controls the 32 LEDs between them.

Peeling the backing at the far end of the LED strip.

At the far end, peel only the final 5 cm of backing paper and secure that last section.

Completed LED strip route viewed from below.

LED strip fitted inside the core.

Stick the last two LEDs on the inside.

Final LED strip placement inside the core.

Remove the backing paper at the beginning of the strip and tape that down too.

## 6. Test the LEDs and fit the controller into the base

Testing the LED strip with USB power.

Before closing the lamp, connect USB power and confirm that the LED strip responds in WLED.

The LED spiral lit for its first test.

With fresh WLED settings, the final five LEDs will probably stay off because the default is 30 LEDs. If you have already configured WLED, the first and final two LEDs stay off as intended.

Cutting double-sided VHB tape for the controller.

Cut about 2 cm² of double-sided VHB tape to hold the ESP32 in the base.

Inside of the lamp base.

The base provides the mounting area for the controller and an opening for its USB port.

Placing the ESP32 in the base.

Remove the tape backing and place the ESP32 in the base, with its USB port facing the opening in the edge.

Core assembly seated in the base.

Lower the wired core assembly into the base. Keep the controller wires inside and make sure nothing is pinched. The core sits inside the rim of the base, with the USB connector still accessible.

Detail of the controller and LED strip in the assembled base.

Push the core all the way down onto the base.

## 7. Fit the diffusor and finish the lamp

Lowering the diffusor over the core.

Lower your chosen diffusor evenly over the LED structure.

Seating the diffusor on the base.

Diffusor fitted over the lamp frame.

Placing the top plug.

Place the top plug into the central opening. It is keyed; turn it until it fits.

Top plug fitted.

Press the top plug down until it clicks into the base.

Finished lamp illuminated.

Connect a 5 V USB supply rated for at least 1.5 A and choose a colour or effect in WLED.

Completed LED mini lamp.

Completed LED mini lamp.

Completed LED mini lamp.

Completed LED mini lamp.

The lamp is ready to use. See [Using your lamp](using-your-lamp.md) for presets, effects, and schedules.

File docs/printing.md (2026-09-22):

# Printing the PLA parts

This page is the print plan for the LED Mini Lamp. Each part is supplied as an
STL and, where available, as a 3MF slicer project. Both formats are already in
the correct printing orientation.

All parts are designed for a **0.4 mm nozzle**. **No supports or brims are
needed**. A few bridges are present, but they are designed to print on almost
any printer.

## Material

All supplied print settings are for **PLA** and were tested with **Prusament
PLA**. Print the diffusors in **white PLA** so they work as intended. For the
core structure, base, top plug, and clip, choose any PLA colour you like.

## What to print

### Core structure — print 3

Print **three** copies of the core structure.

**Print settings**

- **0.28 mm draft** layer height is suitable; this part is not critical.
- Use **15% infill or more**.

| Part | STL | Print volume (X × Y × Z) | 3MF |
| --- | --- | --- | --- |
| Core structure | [STL](../print-files/stl/lamp_core_structure.stl) | 94 × 94 × 25 mm | [3MF](../print-files/3mf/lamp_core_structure.3mf) |

### Standard parts

Print one of each of these standard parts.

**Print settings**

- **0.28 mm draft** layer height is suitable; these parts are not critical.
- Use **15% infill or more**.

| Part | STL | Print volume (X × Y × Z) | 3MF |
| --- | --- | --- | --- |
| Lamp base | [STL](../print-files/stl/lamp_base.stl) | 100 × 100 × 16 mm | [3MF](../print-files/3mf/lamp_base.3mf) |
| Top plug | [STL](../print-files/stl/lamp_top_plug.stl) | 60 × 60 × 33.3 mm | [3MF](../print-files/3mf/lamp_top_plug.3mf) |

The top plug's 3MF uses **6 bottom layers** to block light from the LEDs
when printed in white PLA.

### Clip unit

The clip uses a finer, stronger print recipe than the standard parts. Open the
dedicated 3MF project when possible.

**Print settings**

- Layer height: **0.10 mm**
- **4 perimeters**
- **100% infill**

| Part | STL | Print volume (X × Y × Z) | 3MF |
| --- | --- | --- | --- |
| Clip unit | [STL](../print-files/stl/lamp_clip_unit.stl) | 15 × 36 × 6 mm | [3MF](../print-files/3mf/lamp_clip_unit.3mf) |

### Diffusors — choose one or more

The diffusor is the visible shade of the lamp. Pick any design below; you can
print more than one to swap the appearance of the lamp later. Use **white PLA**.

Diffusors need their own recipe: do not print them with the standard-part
settings. Vase mode and the controlled bottom thickness are important, so open
the dedicated 3MF project when possible.

**Print settings**

- Recommended layer height: **0.20 mm**
- Enable **vase mode**.
- Use enough bottom layers to make a base **about 1.4–1.5 mm thick**. At
  0.20 mm layer height, this is **7 bottom layers**. Adjust the layer count if
  you use a different layer height.

| Design | STL | Print volume (X × Y × Z) | 3MF |
| --- | --- | --- | --- |
| Bulges | [STL](../print-files/stl/lamp_diffusor_bulges.stl) | 102.7 × 102.7 × 50 mm | [3MF](../print-files/3mf/lamp_diffusor_bulges.3mf) |
| Pumpkin | [STL](../print-files/stl/lamp_diffusor_pumpkin.stl) | 111.2 × 110.8 × 50 mm | [3MF](../print-files/3mf/lamp_diffusor_pumpkin.3mf) |
| Seven ripple | [STL](../print-files/stl/lamp_diffusor_seven_ripple.stl) | 103.2 × 103.2 × 50 mm | [3MF](../print-files/3mf/lamp_diffusor_seven_ripple.3mf) |
| Single sinusoidal bulge | [STL](../print-files/stl/lamp_diffusor_single_sinusoidal_bulge.stl) | 119.9 × 119.9 × 50 mm | [3MF](../print-files/3mf/lamp_diffusor_single_sinusoidal_bulge.3mf) |
| Sinusoidal 12 bubbles | [STL](../print-files/stl/lamp_diffusor_sinusoidal_12_bubbles.stl) | 103.4 × 103.4 × 50 mm | [3MF](../print-files/3mf/lamp_diffusor_sinusoidal_12_bubbles.3mf) |
| Sinusoidal 36 wave ×3 | [STL](../print-files/stl/lamp_diffusor_sinusoidal_36_wave_x3.stl) | 104.1 × 104.1 × 50 mm | [3MF](../print-files/3mf/lamp_diffusor_sinusoidal_36_wave_x3.3mf) |
| Starburst | [STL](../print-files/stl/lamp_diffusor_starburst.stl) | 106.2 × 106.2 × 50 mm | [3MF](../print-files/3mf/lamp_diffusor_starburst.3mf) |

All seven available lamp diffusor designs, numbered for reference.

The seven available designs: **1** Bulges · **2** Seven ripple · **3** Pumpkin · **4** Single sinusoidal bulge · **5** Starburst · **6** Sinusoidal 36 wave ×3 · **7** Sinusoidal 12 bubbles.

## Estimated print resources

Measured on a **Prusa Core One L** using the supplied 3MF projects. The total
below is for one lamp with **one diffusor** and **three core structures**.
Filament costs use **€24.50/kg**. Actual values vary with filament, slicer,
and printer.

| Part | Filament weight | Filament length | Print time | Filament cost |
| --- | ---: | ---: | ---: | ---: |
| Core structures (3) | 35.25 g | 11.80 m | 55 min | €0.86 |
| Top plug | 17.60 g | 5.90 m | 25 min | €0.43 |
| Clip unit | 1.93 g | 0.65 m | 11 min | €0.05 |
| Lamp base | 27.84 g | 9.34 m | 27 min | €0.68 |
| Diffusor (one) | 18.08 g | 6.06 m | 49 min | €0.44 |
| **Total** | **100.70 g** | **33.75 m** | **2 h 47 min** | **€2.47** |

## Additional print options

For a taller **five-layer lamp**, use the five-layer Bulges diffusor and the
matching longer top plug in place of their standard versions.

For an **ESP32-C3 Super Mini**, choose the modified base with a small cage that
holds the board in place.

| Part | STL | 3MF |
| --- | --- | --- |
| Bulges diffusor — five layers | [STL](../print-files/stl/lamp_diffusor_bulges_5_layers.stl) | [3MF](../print-files/3mf/lamp_diffusor_bulges_5_layers.3mf) |
| Longer top plug — five layers | [STL](../print-files/stl/lamp_top_plug_5_layers.stl) | [3MF](../print-files/3mf/lamp_top_plug_5_layers.3mf) |
| Base — C3 Super Mini | [STL](../print-files/stl/lamp_base_c3_super_mini.stl) | [3MF](../print-files/3mf/lamp_base_c3_super_mini.3mf) |

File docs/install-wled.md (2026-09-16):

# Installing WLED firmware

This page installs WLED on the ESP32. Once WLED is running, continue with the
[lamp-specific WLED setup](wled-setup.md).

## Recommended method: WLED web installer

1. Connect the ESP32 to a computer with a USB **data** cable.
2. Use a current desktop version of Chrome, Edge, Opera, or Firefox.
3. Open the [WLED web installer](https://install.wled.me/).
4. Follow the installer prompts and select the connected ESP32.
5. Choose the WLED firmware appropriate for your ESP32 board and complete the
   installation.

After the ESP32 restarts, it creates the temporary Wi-Fi network `WLED-AP`.
Continue with [WLED setup](wled-setup.md).

## Other installation methods

The browser installer does not suit every ESP32 board or computer. If it does
not work for your setup, use the method recommended for your board and the
[official WLED installation guide](https://kno.wled.ge/basics/install-binary/),
or consult your preferred AI.

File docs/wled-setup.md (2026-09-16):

# Setting up WLED

First [install WLED firmware onto the ESP32](install-wled.md). This page covers
only the lamp-specific configuration after WLED is running.

## App and first connection

Install the free **WLED** app on [Android](https://play.google.com/store/apps/details?id=ca.cgagnier.wlednativeandroid)
or [iOS](https://apps.apple.com/gb/app/wled-native/id6446207239). The app is
useful for finding and controlling the lamp, but the same setup can also be
done in a web browser.

1. Power the lamp through the ESP32 USB port.
2. On a phone or computer, connect to the temporary Wi-Fi network named
   `WLED-AP`. The default password is `wled1234`.

   The WLED-AP network in a phone's Wi-Fi settings.

3. The WLED app usually opens automatically. If it does not, open the app
   manually. As a backup, open [wled.me](http://wled.me) or `http://4.3.2.1`.
4. Open **Config → WiFi & Network**.
5. Enter the name and password of your home Wi-Fi network.

   WLED Wi-Fi and Network Settings showing the network-name and password fields.

6. Optional: set the **mDNS address / hostname** to the name you want for the lamp, for
   example `led-mini-lamp`. It will then be available at
   `http://led-mini-lamp.local` on most home networks.
7. Save the settings. The lamp restarts and joins your home Wi-Fi network.

Reconnect your phone to the same home Wi-Fi network. The WLED app should find
the lamp automatically; select it to control it.

Giving the lamp a custom name in the WLED app.

You can also give the lamp a custom name in the WLED app, so it is easy to identify when you have more than one device.

## LED and hardware settings

Open **Config → LED & Hardware** and configure the LED output as follows:

| Setting | Value |
| --- | --- |
| LED type | WS281x |
| LED count | 32 |
| Skip first LEDs | 1 |
| mA/LED | 35 mA (Eco WS2812) |
| Maximum PSU current | 1200 mA |

WLED LED and Hardware settings with the lamp's configured values.

The physical strip has 35 LEDs. The first LED and the final two LEDs are only
used to attach the strip to the structure, so WLED skips the first and controls
only the 32 LEDs in between.

Save the configuration. The lamp is now ready to use from the WLED app or its
web interface.

For WLED installation methods and general troubleshooting, use the
[official WLED documentation](https://kno.wled.ge/basics/getting-started/).

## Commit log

2026-09-11 Initialize project structure
    [bom.csv]
2026-09-11 Remove board-specific firmware setup notes
2026-09-11 Add printable lamp parts
    [lamp_base.3mf, lamp_base.stl, lamp_clip_unit.3mf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]
2026-09-11 Document printable part groups
2026-09-11 Add print settings by part group
2026-09-11 Use diffusor spelling in print guide
2026-09-11 Add Starburst print project and clarify recipes
    [lamp_diffusor_starburst.3mf]
2026-09-11 Document PLA material requirements
2026-09-11 Add part print volumes and common print notes
2026-09-11 Trim core printing guidance
2026-09-11 Add print resource estimates
2026-09-11 Update filament cost estimates
2026-09-11 Add initial bill of materials
    [bom.csv]
2026-09-11 Present bill of materials as Markdown
    [bom.csv]
2026-09-11 Add BOM cost estimates and supplier links
2026-09-11 Clarify flat controller requirement and LED sourcing
2026-09-11 Correct LED strip cost estimate
2026-09-11 Add total estimated material cost
2026-09-11 Integrate printed-parts cost into BOM
2026-09-11 Remove empty CAD placeholder
2026-09-16 Add illustrated assembly guide
2026-09-16 Refine assembly photos and captions
2026-09-16 Clarify LED strip fitting steps
2026-09-16 Clarify LED input and base fitting photos
2026-09-16 Add diffusor overview to printing guide
2026-09-16 Refine assembly preparation captions
2026-09-16 Refine LED strip assembly captions
2026-09-16 Describe first LED strip bend
2026-09-16 Reorder LED strip assembly photos
2026-09-16 Simplify assembly finishing steps
2026-09-16 Add final lamp photos to assembly guide
2026-09-22 Add five-layer lamp parts and C3 Super Mini base
    [lamp_base_c3_super_mini.3mf, lamp_base_c3_super_mini.stl, lamp_diffusor_bulges_5_layers.3mf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]
2026-09-22 Document new print options and thicken top plug bottom layers
    [lamp_top_plug.3mf]
2026-09-23 Widen peg holes and specify double-sided VHB tape
    [lamp_base.3mf, lamp_base.stl, lamp_base_c3_super_mini.3mf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]
